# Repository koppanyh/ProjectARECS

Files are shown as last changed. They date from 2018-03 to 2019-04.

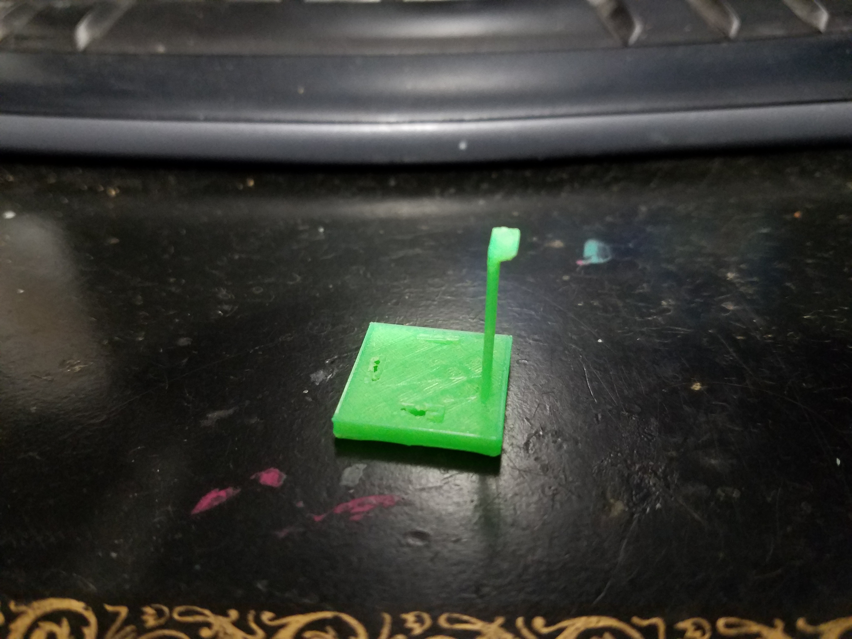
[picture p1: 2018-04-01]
seniorproject/tests/20180330_193834.jpg

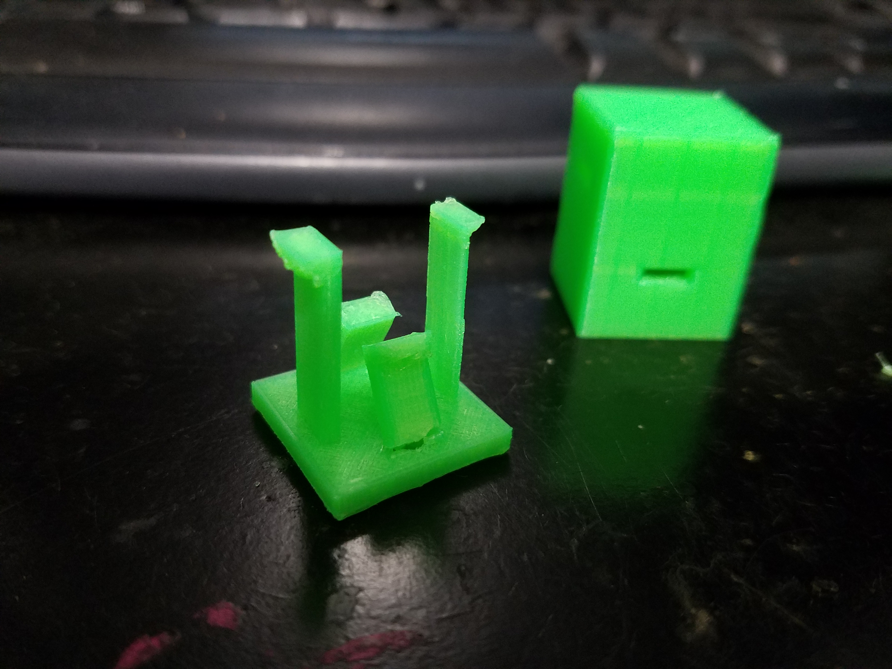
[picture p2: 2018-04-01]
seniorproject/tests/20180330_191624.jpg

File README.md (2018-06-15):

# ProjectARECS
This project is an RFID employee time tracking system.

The acronym ARECS stands for Automatic RFID Employee Clocking System.

This project is both a software and hardware project, the software is for recording and interfacing with data generated by employees, and the hardware part is the RFID nodes that generate events based on the employees.

This was initially done as a senior project during my junior year at the University of La Verne.

The version of this project submitted for the senior project can be found archived in the senior project folder. The files outside of that are the actual project files that are in active development.

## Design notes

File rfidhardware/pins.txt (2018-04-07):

esp32	rc522	piezo	dipsw	buttn	led01	power
3v3		3.3v			all**	all**
gnd		gnd								-		out-
vin												out+
d15				outer
d4				center
d2										+
d5		sda
d18		sck
d19		miso
d22		rst
d23		mosi
d32						0*
d33						1*
d34						2*
d35						3*
d25								0*

* also pulled down to ground
** all pins not directly connected to mcu

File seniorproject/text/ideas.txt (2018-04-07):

toggle thing should keep track of over/under time and give options like "cash out" or "leave early" and stuff

users can't edit records older than 7 days

rfid nodes should have button to become hotspot for on-the-spot configuration

show a super simple interface with an advanced button somewhere, clicking that advanced button will use an animation to drop down the current page and reveal the advanced page underneath

node has to keep records until verified that the server received them

in manager page, show cards of each person with picture, and hours, clicking will take to more detail page with charts and stuff

alert admins of people who just walked in

give flexible query capabilities for admins

qr codes on the id cards for quick scan

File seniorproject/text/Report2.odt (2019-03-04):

UNIVERSITY OF LA VERNE

LA VERNE, CALIFORNIA

Spring 2018

SENIOR PROJECT REPORT

J2 INNOVATIONS’ AUTOMATIC RFID EMPLOYEE CLOCKING SYSTEM

A SENIOR PROJECT SUBMITTED TO:

THE FACULTY OF

COMPUTER SCIENCE AND COMPUTER ENGINEERING

IN CANDIDACY FOR THE DEGREE OF

BACHELORS OF SCIENCE

SOFTWARE / ENGINEERING

BY

KOPPANY HORVATH

# Abstract

The purpose of this project is to design and implement an RFID based employee time tracking system for J2 Innovations, a building automation software company. The following hardware technologies were used: IOT enabled ESP 32 microcontroller, RFID scanner module, 3D printing, WiFi AP device configuration. In addition, a variety of software was used: Arduino IDE, NodeJS framework, Ractive library, AM Charts library, MySQL database. The user experience was greatly improved and user complaints were reduced to nearly none. Possible future expansions include handling different time zones for international employees, generating reports and charts for management, and scheduling days off and vacations through the UI.

# Chapter I: Introduction

## Introduction

When tasked with overseeing employee work times and productivity, how that data is obtained and managed can be the difference between a good or bad user experience. The point of this study is to design and implement a system that can improve how employees log their work hours and tasks, along with making it easy for management to manage that information. The proposed design directly relates to the problem in that it attempts to solve the problems present in the previous system for tracking employee work times. This study relates to previous work in that it uses RFID technology to acquire parts of the data, but it is applied to tracking the time of employees rather than tracking the locations of materials.

## Problem Statement

The employees and management working for J2 Innovations, a building automation software company, are frequently annoyed by the current time tracking system being used. One of the biggest problems that management complains about is that the system is a third party service that requires monthly payment per registered employee, and is not flexible in terms of adding new features or correcting problems with the service. An issue that bothers the employees is that with the current system employees have to manually type in their starting time and ending time which sometimes results in inaccurate information if an employee can't remember their starting time accurately. The project manager is sometimes bothered by not being able to see what the general schedule is for part time employees who have very dynamic schedules through the web interface of the current system. Employees also don’t like having to submit a daily email containing their work for the day along with a weekly email containing not only the information from the daily emails, but what their times were for each day that they worked because the current system has no easy way for management to view this information.

## Purpose Statement and Rationale

The purpose of this project is to design and build an RFID based employee time tracking system to address the issues caused by J2 Innovations’ current time tracking system. This new system will solve the problem of monthly payment by running on a local server rather than as a remote paid service and will solve the problem of being inflexible by being made open source and being designed to be easily modifyable. This system will also solve the problem of employees having to manually type their times by using RFID technology to automatically record that information by swiping an RFID card on an RFID node. The web interface for this system will also allow management to view the schedules of employees and view their times along with the tasks they did throughout the day.

## Method

The method of this study consisted of doing initial research to see what previous approaches to the problem had been attempted. Then more research followed to investigate a good way to implement the server software which would work to manage data and route data where it needs to be. Then research was done to see what kind of IOT configurations are generally easy to use.

After research, software implementation testing followed to determine the effectiveness of the chosen implementation. Shortly after software implementation began, the focus changed to hardware testing to see how well the components would fit together and to learn the concepts of IOT programming which would be used in the final hardware product.

Following hardware and software testing, production level implementations began. Hardware had the highest initial priority, with software coming in second in order to provide any web API support that the IOT part of the hardware required. After hardware had been finished, it was tested in 2 physical locations to make sure it worked. The software implementation continued on after that to implement all basic functionality needed by the end users.

## Need of Such a Project

This project was necessary in order to address the problems described in the Problem Statement section. Most important of those problems was to make a dynamic system that did not require payment to a 3rd party service which increases in proportion to the amount of employees using the system. This problem alone justifies the need for such a project as far as management is concerned. A quick poll of the employees also reveals that they collectively do not like the current system and even though they are skeptical about the effectiveness of this new system, they would still be willing to try the new system.

## Contributions to Knowledge and Society

Unfortunately, due to the limited nature of the Senior Project, this project does nothing particularly special to contribute to humanity's collective knowledge. However, this project has been open-source since the start and is freely available on GitHub. It is hoped that this project might be used at other companies where a free employee time tracking system would be beneficial along with all the convenience features that it provides.

## Limitations

The major limitations of this project in its current state are as follows. End users from different timezones other than the one that the server is being hosted at will notice that some of the timestamps will be incorrect. Management still doesn't have fine control over individual reports as the current implementation focuses on mass reports and data. From an IT standpoint, someone well versed in Linux based server systems will be required to install and maintain the server software. These issues are expected to be resolved in future updates of this project.

# Chapter II: Literature Review

## Historical Implementations

In conducting research, three notable implementations of digital employee time tracking systems were found. The first, Office Timesheet 2000, has the capability to clock workers in and out, along with being able to record time spent working on separate projects or tasks. The interface comes as a desktop application or as a primitive “web app”. Timesheet 2000 uses a client-server architecture with the ability to store data in a variety of database applications. This system also supports dynamic reports and the capability to send automatic email notifications (Feibus).

The second time tracking system, TimeSheet Pro, is very similar to Office Timesheet 2000 in its main features, but is designed to be more configurable. This system can either use database applications to store data, or it can store data locally. Like Timesheet 2000, TimeSheet Pro can track projects and tasks and be accessed through a web browser. Unlike Timesheet 2000, TimeSheet Pro is more configurable in terms of holidays, task rules, and pay rules. TimeSheet Pro is also considered more difficult to use due to poor design of the user interface (Feibus).

The third time tracking system is called Employee Proj Clock. This system is designed as a small desktop application that communicates with a server to retrieve and transfer information. Each user can only edit their own information, or an administrator can edit anyone's information. The interface is simple in that the basic inputs are the project to be worked on, who the user is, when they started, when they ended, and any comments the user might have. This information is sent to the server and recorded into a database. A custom reports tool allows reports to be built based on what information is required. It is reported that Employee Proj Clock improves productivity and accuracy of time records when switching over from traditional time cards or manual reporting (Gruber).

## Modern Implementations

During research, three modern examples of employee time tracking systems were discovered. The first, Syspro ShopClock, is a real-time data collection system for employee time and attendance. ShopClock can also track the time spent on jobs and materials used in performing a task. This system gives management a GANTT chart that updates in real time to display the status of employees. ShopClock allows for shifts, labor rates, and overtime pay to be defined in advance. ShopClock can also integrate with barcode readers to update the materials used and current inventory. When employees are clocking in or out, ShopClock will alert the user if there is a problem with the information that they are inputting (Syspro).

The second system is Replicon's Cloud Clock, which is a cloud based time clock. This implementation is unique in that it uses an internet connected hardware clock that the users interact with while giving management the power to monitor who clocks in and when. Along with the hardware clock, Replicon offers its Cloud Clock software as a service. This allows management to validate attendance records and ensure compliance of work policy. Replicon reported that compliance for employees submitting completed timesheets increased by 85% while reducing payroll errors from 8% to just 1.9% in less than a year (Replicon).

The last example is the TSheets employee time tracking system. What is unique about this system is how much effort the developers put into making the system as fun and easy to use as possible. TSheets has moved away from relying on dedicated hardware for tracking time and instead uses a cloud based solution with phone apps and web apps so that employees can use any device they want to clock in and out. TSheets also logs employees locations as they use the system so that employees can't cheat on attendance reports because management will know that they weren't really where they said they were when they clocked in. TSheets even has a rating system so that they can know how satisfied employees are with the overall system and its features (Computers).

## RFID Systems

Due to this project using RFID technology, research on examples of using RFID technology on humans was necessary. Unfortunately, using RFID for the purpose of tracking employee times does not seem to be something that has been reported in any journals, and thus the following examples are used for purposes other than employee time tracking. The first example is a study trying to determine the best way of utilizing RFID technology in a hospital setting to track tools and equipment throughout the building as well as patients. Of greatest interest in this study were the results and conclusions that the research group came up with while reviewing different RFID implementations. In the comparison between active and passive RFID technology, it was found that while passive RFID has a smaller detection range, it is still a better option due to the RFID tags being smaller and cheaper when compared to active RFID tags. During testing with actual passive RFID hardware, the researchers found out that the RFID tags could only be read when the face of the tag was parallel to that of the RFID reader, and it had trouble being read when in direct contact with a human body or when it was attached to some objects with a high liquid content. Eventually it was discovered that passive RFID technology has many limitations, but is acceptable because of the cost and size factors (Najera).

The second example is a study attempting to determine the effectiveness of RFID technology in collecting data from a construction site in order to be analyzed for better decision making to improve productivity. Like the previous study, the researchers in this study came to the same conclusion that passive RFID technology was better suited than active RFID technology because the tags are smaller and cheaper, even despite certain problems caused by RFID signals being attenuated by metal beams within the walls of the construction site. Also like the previous study, these researchers found that passive RFID technology has a relatively small detection range, but they were able to solve this problem by strategically positioning the RFID readers in places that would come as close as possible to where materials and workers with tags would be passing by such as doorways (Costin).

# Chapter III: Analysis

## Feasibility Study

In studying other works to determine the feasibility of this project, along with what requirements are needed for this project, a conclusion was reached in that this project is quite feasible. This conclusion was reached because all of the necessary hardware and software technologies could be found as commercial off-the-shelf modules and libraries that would make implementation of this project possible within the deadline of the Senior Project.

## Analysis of Findings From Previous Chapter

Based on the research from the previous chapter, there are common patterns that seem to be standard of employee time tracking systems. The biggest commonality that stuck out was the use of client-server architecture when implementing such a system. One of the systems, TimeSheet Pro, had the ability to store data locally, but could also use a remote database if necessary. Otherwise, the other systems exclusively used a client-server setup to keep the stored data centralized on a server and give the end users either a web interface to work with, or API calls for desktop applications that interface with the server.

The next most common implementation feature was the use of a web page interface to interact with the employee time tracking system. With the exception of Employee Proj Clock, the other platforms at least offered some form of web interface, even if a desktop application was the main interface for that system. In comparing the more modern systems with the older systems, it appears that a web app style interface is preferred over a desktop application style interface.

One smaller common feature that was found to be common during research is adding features other than employee time tracking. This seems to give the system a greater market advantage because everything can be managed with one system as opposed to multiple systems. Examples of this are tying it into the inventory system as in SysPro's ShopClock. Another example is tying in physical time tracking hardware as in Replicon's Cloud Clock.

In terms of RFID technology implementation, a preference between the two RFID types was detected as well. With RFID technology, there are two kinds, active and passive. Active RFID transmits data from the RFID tag to the RFID scanner, passive RFID is powered by the RFID scanner and communicates through backscattering. Because active RFID transmits by itself, it requires a power source such as a battery, which when compared to passive RFID, makes it a very bulky option since passive RFID is capable of data transfer without having any on-board power. Unfortunately, since passive RFID is wirelessly powered through the RFID scanner and does not broadcast by itself, the data transfer distance is very short, usually a few centimeters for low cost off-the-shelf modules.

## Hardware and Software Choices

After understanding the basics of an employee time tracking system along with the basics of RFID implementations, choices can now be made about the kind of hardware and software that would be needed to accomplish a project that combines both together. Because the software is going to be supporting the hardware in this project, it would be helpful to know about the hardware first. For RFID communication, a passive approach is preferred due to its low cost. The MFRC522 RFID module satisfies this requirement and is commercially available, even at the hobbyist level. Since the RFID node will also need some data processing capabilities along with network communication to send data to a main server, the decision to go with the ESP32 microcontroller was made. This microcontroller is relatively cheap, has WiFi networking capabilities, is easy to program, and is also commercially available.

With the main hardware components having been chosen, choosing what software to use comes next. Because of the need of a main server that the hardware will communicate to and that users will interface with, the Node.js framework was chosen. This allows for the customization of every aspect of the web server and the API that will be needed to manage everything. Since the server will also be used for serving up the web interface for the users, the standard languages of the web will be used, HTML, CSS, and JavaScript. In order to facilitate faster development of the interface, a dynamic template framework known as Ractive will be used on the client side as well. For data storage, a MySQL database will be used due to its proven reliability and ubiquity.

# Chapter IV: Design

## Overview

In order to put the pieces together and build this project, everything had to be designed first. Since there is an idea of how the users will use the system, that provides an entry point into the basic system design. The user will scan their RFID card with the RFID node. The RFID node will report to the server that the user has just scanned their card. The server will clock the user in for the day. From there the user can use the web interface from the server to interact with the data. A diagram of this basic architecture can be found in Appendix C as Figure 1.

Knowing what the architecture of this project is helps to generate a workflow for the users, which in turn will help to better design the software to meet the workflow. Figure 2 in Appendix C shows the basic workflow of the user. When users walk into work in the morning, they scan their RFID card with the RFID node. This clocks the user in and allows them to start working. As the user works on tasks or projects that they have been assigned, the user can use the web interface to log them individually. This gives management a better idea of what was done between clocking in and clocking out that day. Once the user has finished working for the day, the user scans his card as he walks out to indicate that he is clocking out. The next day the cycle is repeated and the system keeps track of it all.

## RFID Hardware

Having defined the functionality of the hardware of this project, it can now be designed fully. The hardware, referred to as “the RFID node”, must be able to scan the user's RFID card when presented with it, and report this to the server for recording purposes. As is generally considered good design, the hardware should also provide some sort of feedback to the user if scanning and reporting to the server was successful or if it had failed.

In the Hardware and Software Choices section of Chapter III, two of the main hardware components were already described. The first was the MFRC522 RFID module, this is the part that will be able to read the unique serial number from an RFID card so that it knows which user has been scanned in. The second was the ESP32 microcontroller, this part interfaces with the RFID module, does whatever processing is required of the data, then packages it up and sends it to the server to be recorded.

However, more components are needed since these two alone do not provide feedback to the user, nor do they provide any form of reconfigurability of the hardware. To address the issue of feedback, it would be best to have both auditory feedback and visual feedback in the event that the user either can't hear the feedback (due to environmental noise) or cannot see the feedback (due to not having a line-of-sight) to the device. The simplest and most common choice for visual feedback is an LED, this would allow it to blink with certain patterns based on what type of feedback the RFID node is trying to convey. For auditory feedback a small speaker would work to provide different tones that hint at states like success or failure. This small speaker is chosen to be a piezoelectric disk speaker due to its extremely low profile and low power use.

To address the problem of hardware reconfigurability, buttons and switches are the simplest and most intuitive interfaces. In the case of this RFID node design, a 4-bit DIP switch would be sufficient for providing 16 total user-defined values to give the hardware a unique address. A momentary push button would also provide the mechanism with which to launch the RFID node into access point mode so that it can be configured over WiFi.

In Appendix C, Figure 3 is a block diagram that shows how all the hardware components will be connected together. Since this RFID node will be running on electricity, a power jack and voltage regulator have been added as well to supply the energy needed to run all parts of the RFID node. The diagram shows the LED and speaker as outputs of the system. The RFID module, DIP switch, button, and voltage regulator are shown as inputs to the system. The system itself is run by the ESP32 microcontroller which is shown in the center of the diagram. This is the piece which will be accepting the inputs and delivering the outputs.

## RFID Firmware

Of course, the hardware cannot just automatically know how to work together when there is a microcontroller in the middle, therefore firmware is needed to tell the microcontroller how to coordinate everything. The firmware must be able to get the data from the RFID module, prepare it for transmission to the server, then send it to the server. While this is happening, the firmware must also be able to control the LED and speaker to alert the user as to the current state of the RFID node. Since the RFID node is designed to be configured over WiFi, an access point mode must also exist within the firmware that can be triggered from the normal operation mode.

Figure 4 in Appendix C is a flow chart that shows the basic operation of the RFID firmware. This flow chart does not include details about certain implementation details, or details about error handling modes. Initially, the mode of the RFID node doesn’t matter until after it boots up. On boot, the firmware gets the state of the DIP switch to get the user-defined 4 bit number in hexadecimal. Then the on-chip unique identifier gets read and has its least significant nibble replaced with the 4 bit DIP switch number. Then the firmware causes the speaker to make a generic beep to indicate that it successfully booted up.

After this point, the firmware looks into persistent memory to see which mode it should be in, either normal RFID scanning mode or access point configuration mode. If the mode is scanning mode, then the firmware reads the WiFi SSID, WiFi password, address of the time tracking server, and server port from the persistent memory and stores them into string variables. Then the firmware connects to the specified WiFi network. If connection is unsuccessful, then the firmware will give a failure beep and go into a loop where the LED blinks SOS in morse code and tries to connect to the WiFi over and over (this an error mode not in Figure 4).

Once a WiFi connection is established, the firmware will attempt to contact the time tracking server to get the current time. If the server cannot be reached, the firmware will make a failure beep and use a Unix timestamp of 0, it will periodically attempt to contact the server to get the current time (this is an error mode not in Figure 4). Then the firmware will create a queue to store up to 256 RFID scan records in the event that they could not be communicated to the server immediately (not in Figure 4).At this point there will be another general beep to alert the user that the RFID node is ready to start scanning RFID cards.

The firmware then enters a loop where it first checks to see if the access point configuration button has been pressed. If it has been pressed, then the firmware will set the mode record in persistent memory to be access point mode, then it will give a general beep 3 times to indicate that it is preparing to go into access point mode. Then it reboots the node so that it may go through the boot process and get to the point where it checks which mode to be in. More on the access point mode will be discussed after the general operation mode is discussed.

After checking the access point button, the firmware asks the RFID module if there is a card waiting to be scanned. If so, then the LED is turned off to show that the RFID card is being read, a scan beep is made, a RFID scan record is made containing the time the card was scanned along with the serial number of the card, the record is sent to the server, then the LED is turned back on. If the server replies that the scan was invalid, then an error beep is made. If the RFID scan record could not be sent to the server, it will be stored in the queue and an error beep will be made (this is an error mode not in Figure 4).

The firmware then continues the loop by checking to see if it has been an hour since the time was last updated or if the time was not updated during boot. If so, then the time is requested from the server and updated (not in Figure 4). Following this, the firmware checks the queue to see if there are any unsent RFID records and attempts to send them if possible (this is an error mode not in Figure 4). The loop then starts from the beginning after this point.

As stated above, the access point mode can be discussed after the general operation mode. After the first general boot beep, when the firmware is checking the mode to see which mode to start, if the mode is access point configuration mode, then the firmware runs the other half of the code. The first thing it does in access point mode is to generate an SSID with the form of “Arecs_Node_X” where X is the uppercase hexadecimal value of the DIP switch nibble (not in Figure 4). Then it generates a password with the form “passwordX” where X is the same uppercase hexadecimal value (not in Figure 4). With this SSID the firmware becomes a WiFi access point that broadcasts the SSID which can be connected to with the password.

After starting the access point, the firmware then sets up the web interface and all the API calls that are needed to support the web interface and apply configuration options. The web interface, which can be seen as Figure 5 in Appendix C, shows the modified unique identifier, inputs for the WiFi network to connect to, and inputs for the RFID server to connect to. The API calls that the web interface has access to can be seen in Figure 6 of Appendix C. The web interface uses a JavaScript AJAX call to “/getssids” to get a list of WiFi networks that the RFID node can connect to, this populates the WiFi network selector in Figure 5.

Once the configuration web interface has been filled out, clicking “Save Configuration” (Figure 5) will send the data as a POST request to the “/configure” API call. This will save the WiFi options if both password fields have been filled out. If the passwords do not match, then it will redirect to the web interface for correction (not shown in Figure 6). The “/configure” API will also save the RFID server parameters if the address of the server is filled in. Once finished, it will set the mode to be scanning mode and then return a web page to prompt a node restart in order to apply the changes. Clicking restart will call the “/restart” API call and restart the server so it may start up in scanning mode.

After defining the web interface and API calls, the firmware then starts up a DNS server. This is so that navigating to any website while connected to the access point will direct you to the configuration web interface page, this technique is known as a captive portal. The firmware will then cause a specific access point beep and blink the LED slowly to let the user know that the access point is up and ready to be connected to. The firmware continues this until the user submits the configuration and restarts the node.

## RFID Enclosure

After the hardware had been designed, it was obvious that it would need to be put into an enclosure to protect it from the users and to give it a professional appearance. A tool-less approach to the enclosure was preferred as this would allow for ease of maintenance and configuration of the DIP switch without requiring tools or force to open the enclosure. With this tool-less requirement, a snap-fit mechanism seemed obvious for holding the enclosure together and making it easy to open without tools. It works by having a base with flexible beams with something like a hook at the end that gets caught in indentations in the lid (refer to Figure 7 of Appendix C). They can then be opened by pushing the beams inward to release the hooks from the indentations.

After a bit of design and testing of snap-fit mechanisms (more about this in the RFID Enclosure section of the Implementation chapter), a final snap-fit test piece was designed and made. The outline of the design of this test piece can be seen as Figure 7 of Appendix C, and the piece made from the design can be found as Figure 8. Unfortunately, this piece broke during a demonstration and was no longer considered a valid design, especially when combined with the failure of previous snap-fit tests (more on this in the Implementation chapter).

A new design was needed to replace the snap-fit concept, but that would still provide the tool-less features of the snap-fit mechanism. This new design was inspired by the snap-fit mechanism and a latch mechanism. The final version of this design can be found as Figure 9 of Appendix C. This new mechanism to hold the enclosure together is referred to as a pin-lock or pin-latch mechanism, but the true name of this mechanism is unknown since mechanisms similar to it could not be found. This mechanism also went through a few design and test stages before leading to this final version (more on this in the Implementation chapter).

The pin-latch mechanism works by having one side of the lid (light gray on the left of Figure 9) held down by something like a reinforced snap-fit joint that doesn't actually snap (dark gray on the left of Figure 9). The lid is able to somewhat hinge on and off of this reinforced snap when the pin (black on the right of Figure 9) is not present. When the pin is present, it prevents the right side of the lid from lifting off of the base (dark gray of Figure 9), and therefore it cannot hinge open and disengage from the snap on the left. The pin uses a snap-fit mechanism to hold itself in place, but this is not a load-bearing snap-fit joint. An image of a physical test piece using this design can be found as Figure 10 of Appendix C.

With the mechanism to hold the enclosure together figured out, the actual enclosure of the RFID hardware could finally be designed. The layout was designed by arranging the hardware components on a piece of paper until a compact and efficient layout was found (Figure 11 of Appendix C). The final design for this enclosure can be found as Figure 12 of Appendix C. The basic design consisted of a base where the electronics would be mounted on (green on Figure 12), a lid to cover everything up (gray on Figure 12), a riser to hold the RFID module close to the surface of the lid (blue on Figure 12), and the pins of the pin-latch mechanism (yellow on Figure 12).

The area of the base (green) was estimated based on how much space the hardware components took up from the layout in Figure 11 of Appendix C. The base also has holes on it for mounting to a wall, these were designed from measurements taken of the mounting holes of a household smoke detector. There is a hole roughly in the middle for the access point configuration button. There are also the reinforced snaps and the second set of holes for the pins that came from the test design. Finally, the base has a large protrusion between the two pin holes for mounting the power jack.

The lid (gray) has the two holes for the pins, along with a bigger hole in the middle for the power jack to stick out of. There is a hole to the side of the pin holes used for connecting a debug cable to the ESP32 microcontroller in the event that debugging or re-flashing of the firmware is required. The back of the lid has two slots for each of the snaps to hook into.

The pins (yellow) of the enclosure are the exact same design as used by the test piece. The riser (blue) for the RFID module is just a slanted flat surface (to give the crystal oscillator some space under the lid) with legs that have a little extra material at the bottom for gluing to the base.

## Server and Web Software

Since the hardware is not designed to be a standalone product, a server is needed to process and handle the data generated by the RFID nodes. Since that data is also useless unless it can be accessed and manipulated, a front end to the server is required as well.

*talk about database design first

*server designed to be configured with db.key file

(elaborate on logic and how you programmed everything)

(the way everything works)

(flow charts, explain them)

(what algorithms and why)

Chapter V: Implementation

RFID Hardware

RFID Firmware

RFID Enclosure

*during implementation it was learned that pla plastic was too rigid to provide the flexibility for snap-fit

Server and Web Software

Chapter VI: Conclusion

Summary and Conclusion

Data

Discussion

Implications

Personal Reflection

Lessons Learned

If It Had To Be Redone

Future Research and Recommendations

Project Recommendations

# References

Computers, software; employees and employers share the love with online time tracking. 2013. Computer Weekly News, May 02. http://0- search.proquest.com.leopac.ulv.edu/docview/1341082761?accountid=25355.

Costin, Aaron, et al. “Leveraging Passive RFID Technology for Construction Resource Field Mobility and Status Monitoring in a High-Rise Renovation Project.” Automation in Construction, vol. 24, July 2012, pp. 1–15., doi:10.1016/j.autcon.2012.02.015.

Feibus, Andy. 1999. Automated time-trackers. InformationWeek no. 742: 53-56, http://0- search.proquest.com.leopac.ulv.edu/docview/229141683?accountid=25355.

Gruber, Elizabeth M. 2001. Project time tracking. Modern Machine Shop 74, no. 1: 203, http://0- search.proquest.com.leopac.ulv.edu/docview/213704139?accountid=25355.

Najera, Pablo, et al. “Real-Time Location and Inpatient Care Systems Based on Passive RFID.” Journal of Network and Computer Applications, vol. 34, no. 3, May 2011, pp. 980–989., doi:10.1016/j.jnca.2010.04.011.

Replicon releases cloud clock for tracking employee time. 2011. Wireless News, http://0- search.proquest.com.leopac.ulv.edu/docview/904432535?accountid=25355.

Syspro rolls out real-time employee tracking solution. 2007. Wireless News: 1, http://0- search.proquest.com.leopac.ulv.edu/docview/210111631?accountid=25355.

Appendices

Appendix A: Gantts Chart

Appendix B: Source Code

Appendix C: Diagrams

Figure 1: Basic system architecture

Figure 2: Non-management employee workflow

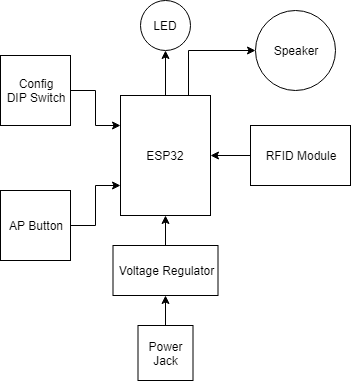
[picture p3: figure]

Figure 3: RFID hardware connection block diagram

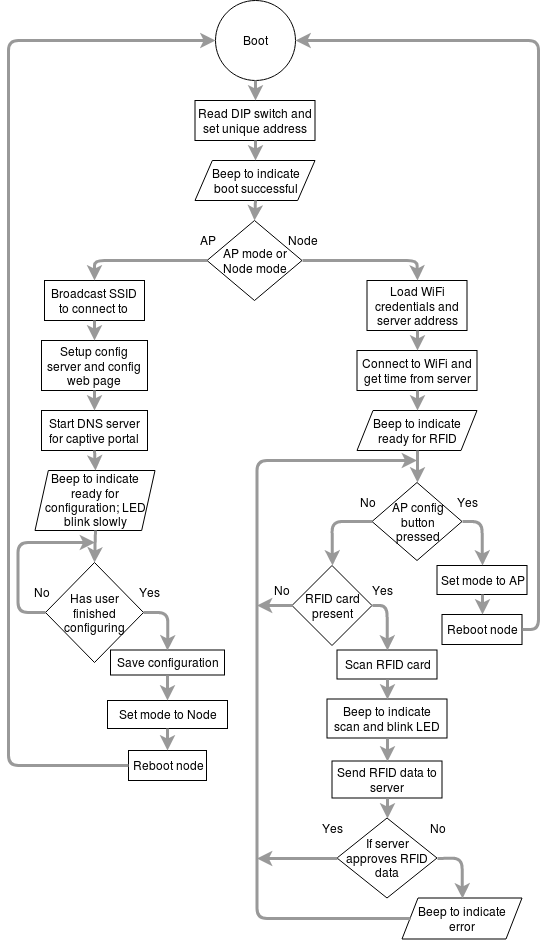
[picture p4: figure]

Figure 4: Firmware flowchart for RFID node

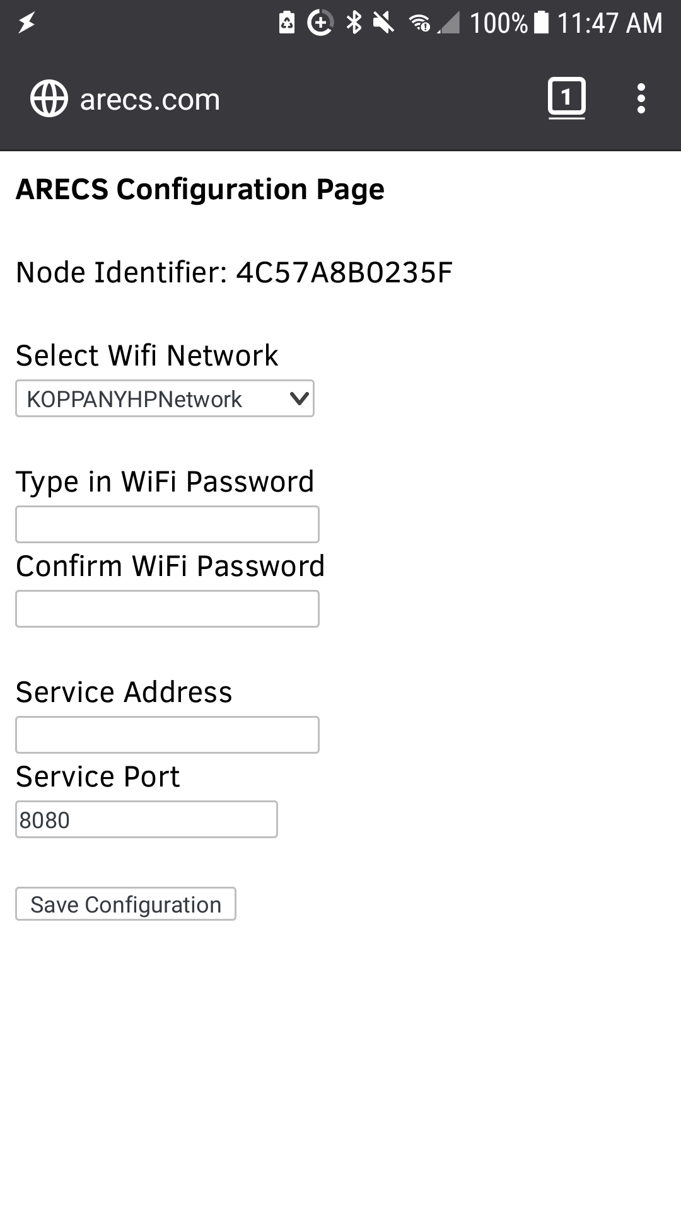
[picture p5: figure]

Figure 5: AP configuration web interface

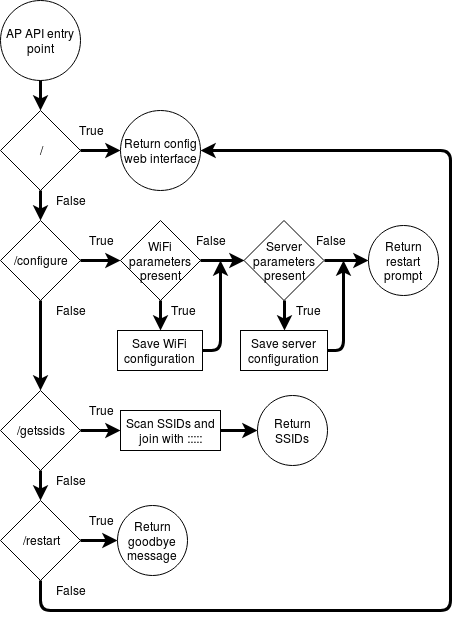
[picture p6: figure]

Figure 6: API flowchart for RFID node AP firmware

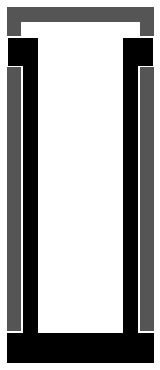
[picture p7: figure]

Figure 7: Design of snap-fit test piece

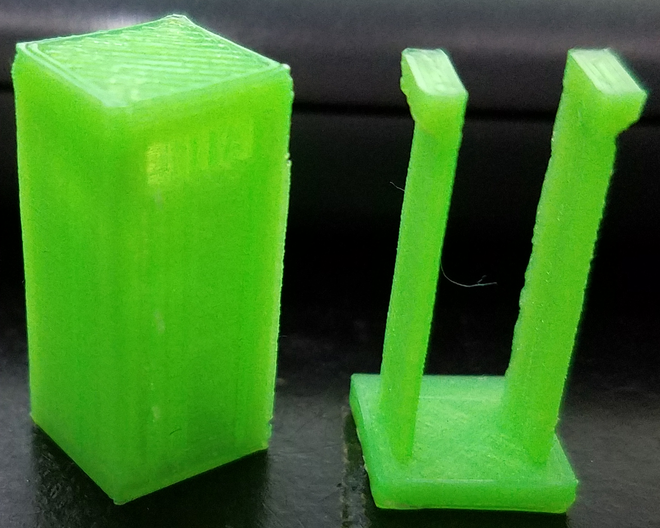
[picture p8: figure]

Figure 8: Physical snap-fit test piece

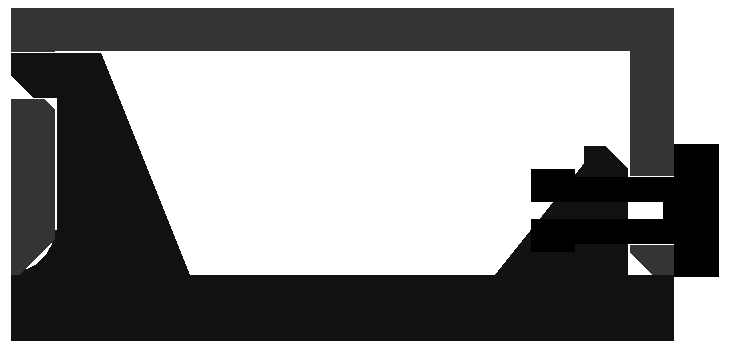
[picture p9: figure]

Figure 9: Design of pin-latch test piece

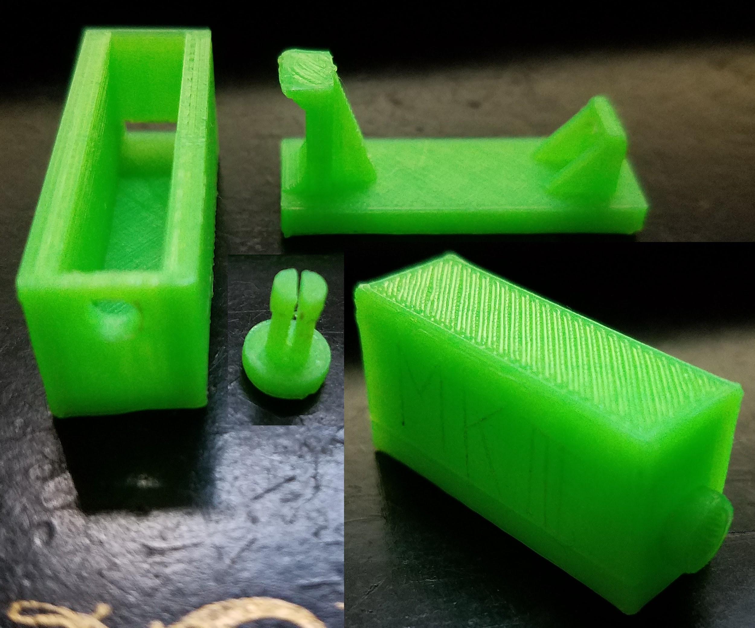
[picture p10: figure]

Figure 10: Physical pin-latch test piece

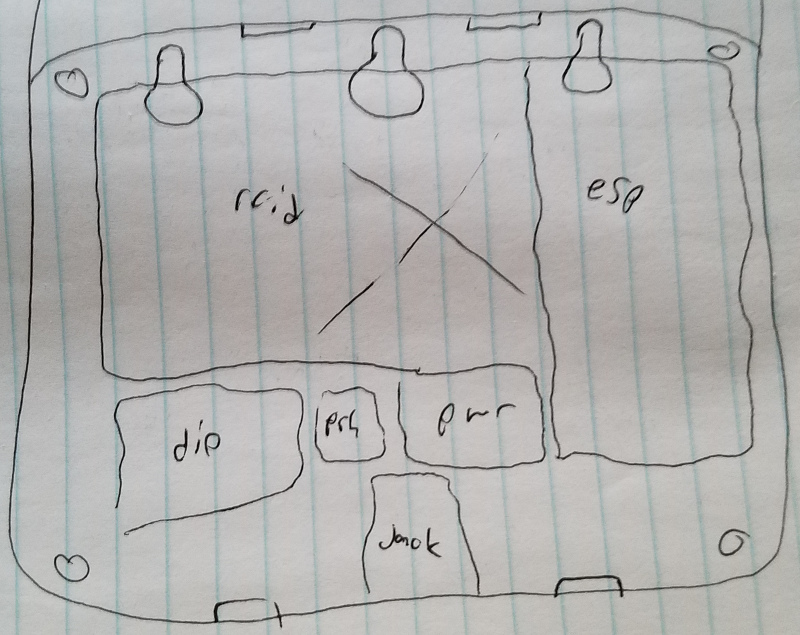
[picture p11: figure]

Figure 11: Hardware layout designed on paper

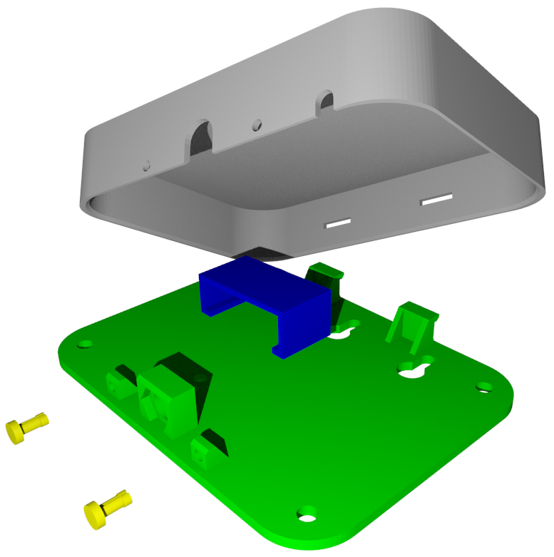
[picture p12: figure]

Figure 12: Enclosure design using pin-latch mechanism

Appendix D: Proposal

Appendix E: PowerPoint

J2 INNOVATIONS’ AUTOMATIC RFID EMPLOYEE CLOCKING SYSTEM ii

Koppany Horvath 2019-03-03

J2 INNOVATIONS’ AUTOMATIC RFID EMPLOYEE CLOCKING SYSTEM 28

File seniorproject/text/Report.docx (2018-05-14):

# UNIVERSITY OF LA VERNE

# LA VERNE, CALIFORNIA

# Spring 2018

# SENIOR PROJECT REPORT

J2 INNOVATIONS’ AUTOMATIC RFID EMPLOYEE CLOCKING SYSTEM

# A SENIOR PROJECT SUBMITTED TO:

# THE FACULTY OF

# COMPUTER SCIENCE AND COMPUTER ENGINEERING

# IN CANDIDANCY FOR THE DEGREE OF

# BACHELORS OF SCIENCE

# SOFTWARE / ENGINEERING

# BY

# KOPPANY HORVATH

# Abstract

The purpose of this project is to design and implement an RFID based employee time tracking system for J2 Innovations, a building automation software company. The following hardware technologies were used: IOT enabled ESP (Whitby & Neely, 2018) 32 microcontroller, RFID scanner module, 3D printing, WiFi AP device configuration. In addition, a variety of software was used: Arduino IDE, NodeJS framework, Ractive library, AM Charts library, MySQL database. The user experience was greatly improved and user complaints were reduced to nearly none. Possible future expansions include handling different time zones for international employees, generating reports and charts for management, and scheduling days off and vacations through the UI.

# Introduction

Keeping accurate records of employee work times is very important. Not only does it ensure that the employees get paid for what they worked, but it also makes sure that conflicts arising from accidental overpaying or underpaying do not occur. Accurate time records also allow for the possibility of measuring work performance when coupled with descriptions of what was done during those hours. Using this information to modify the working environment and schedules can lead to higher productivity in a company.

- What is the point if the study?
- How does the proposed design relate to the problem?
- What are the implications of the study, and how does the study relate to previous work in the area?
- What are current pro[positions tested, and how were they derived?

A good introduction answer these questions in a paragraph or two and, by summarizing the relevant arguments and the data, gives the reader a firm sense of what was done and why.

Develop the background:

Assume that the reader has knowledge in the field for which you are writing and does not require a complete digest. A scholarly review of earlier work provides an appropriate history and recognizes the priority of the work of others. If you summarize earlier works, avoid nonessential details; instead, emphasize pertinent findings, relevant methodological issues, and major conclusion. Refer readers to general surveys or reviews of the topic if they are available. Demonstrate the logical continuity between previous and present work.

State the purpose and rationale:

After you have introduced the problem and developed the background material, you are in a position to tell what you did. Make this statement in the closing paragraph of the introduction.

# Method

Insert method here

# Results

Insert results here

# Discussion

Insert discussion here

# References

# Bibliography

Whitby, S., & Neely, M. (2018). this is a play. MIS Quarterly, 7(2), 9.

# Appendix

Insert appendix here

Koppany Horvath 2018-05-04

J2 INNOVATIONS’ AUTOMATIC RFID EMPLOYEE CLOCKING SYSTEM Page 5 of 6

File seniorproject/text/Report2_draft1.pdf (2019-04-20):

UNIVERSITY OF LA VERNE

LA VERNE, CALIFORNIA

Spring 2019

SENIOR PROJECT REPORT

J2 INNOVATIONS’ AUTOMATIC RFID EMPLOYEE CLOCKING SYSTEM

A SENIOR PROJECT SUBMITTED TO:

THE FACULTY OF

COMPUTER SCIENCE AND COMPUTER ENGINEERING

IN CANDIDACY FOR THE DEGREE OF

BACHELORS OF SCIENCE

SOFTWARE / ENGINEERING

BY

KOPPANY HORVATH

J2 INNOVATIONS’ AUTOMATIC RFID EMPLOYEE CLOCKING SYSTEM | i

## Abstract

The purpose of this project is to design and implement an RFID based employee time

tracking system for J2 Innovations, a building automation software company. The following

hardware technologies were used: IoT enabled ESP 32 microcontroller, RFID scanner module,

3D printing, WiFi AP device configuration. In addition, a variety of software was used: Arduino

IDE, NodeJS framework, Ractive library, AM Charts library, MySQL database. The user

experience was greatly improved and user complaints were reduced to nearly none. Possible

future expansions include handling different time zones for international employees, generating

reports and charts for management, and scheduling days off and vacations through the UI.

Koppany Horvath | 2019-04-19

J2 INNOVATIONS’ AUTOMATIC RFID EMPLOYEE CLOCKING SYSTEM | ii

## Table of Contents

J2 INNOVATIONS’ AUTOMATIC RFID EMPLOYEE CLOCKING SYSTEM | 1

## Chapter I: Introduction

## Introduction

When tasked with overseeing employee work times and productivity, how that data is

obtained and managed can be the difference between a good or bad user experience. The point of

this study is to design and implement a system that can improve how employees log their work

hours and tasks, along with making it easy for management to manage that information. The

proposed design directly relates to the problem in that it attempts to solve the problems present in

the previous system for tracking employee work times. This study relates to previous work in

that it uses RFID technology to acquire parts of the data, but it is applied to tracking the time of

employees rather than tracking the locations of materials.

## Problem Statement

The employees and management working for J2 Innovations, a building automation software

company, are frequently annoyed by the current time tracking system being used. One of the

biggest problems that management complains about is that the system is a third party service that

requires monthly payment per registered employee, and is not flexible in terms of adding new

features or correcting problems with the service. An issue that bothers the employees is that with

the current system employees have to manually type in their starting time and ending time which

sometimes results in inaccurate information if an employee can't remember their starting time

accurately. The project manager is sometimes bothered by not being able to see what the general

schedule is for part time employees who have very dynamic schedules through the web interface of the current system. Employees also don’t like having to submit a daily email containing their

work for the day along with a weekly email containing not only the information from the daily

emails, but what their times were for each day that they worked because the current system has

no easy way for management to view this information.

## Purpose Statement and Rationale

The purpose of this project is to design and build an RFID based employee time tracking

system to address the issues caused by J2 Innovations’ current time tracking system. This new

system will solve the problem of monthly payment by running on a local server rather than as a

remote paid service and will solve the problem of being inflexible by being made open source

and being designed to be easily modifiable. This system will also solve the problem of

employees having to manually type their times by using RFID technology to automatically

record that information by swiping an RFID card on an RFID node. The web interface for this

system will also allow management to view the schedules of employees and view their times

along with the tasks they did throughout the day.

## Method

The method of this study consisted of doing initial research to see what previous approaches

to the problem had been attempted. Then more research followed to investigate a good way to

implement the server software which would work to manage data and route data where it needs

to be. Then research was done to see what kind of IoT configurations are generally easy to use.

After research, software implementation testing followed to determine the effectiveness of

the chosen implementation. Shortly after software implementation began, the focus changed to hardware testing to see how well the components would fit together and to learn the concepts of

IoT programming which would be used in the final hardware product.

Following hardware and software testing, production level implementations began.

Hardware had the highest initial priority, with software coming in second in order to provide any

web API support that the IoT part of the hardware required. After hardware had been finished, it

was tested in 2 physical locations to make sure it worked. The software implementation

continued on after that to implement all basic functionality needed by the end users.

## Need of Such a Project

This project was necessary in order to address the problems described in the Problem

Statement section. Most important of those problems was to make a dynamic system that did not

require payment to a third party service which increases in proportion to the amount of

employees using the system. This problem alone justifies the need for such a project as far as

management is concerned. A quick poll of the employees also reveals that they collectively do

not like the current system and even though they are skeptical about the effectiveness of this new

system, they would still be willing to try the new system.

## Contributions to Knowledge and Society

Unfortunately, due to the limited nature of the Senior Project, this project does nothing

particularly special to contribute to humanity's collective knowledge. However, this project has

been open-source since the start and is freely available on GitHub. It is hoped that this project

might be used at other companies where a free employee time tracking system would be

beneficial along with all the convenience features that it provides.

## Limitations

The major limitations of this project in its current state are as follows. End users from

different time zones other than the one that the server is being hosted at will notice that some of

the timestamps will be incorrect. Management still doesn't have fine control over individual

reports as the current implementation focuses on mass reports and data. From an IT standpoint,

someone well versed in Linux based server systems will be required to install and maintain the

server software. These issues are expected to be resolved in future updates of this project.

## Chapter II: Literature Review

## Historical Implementations

In conducting research, three notable implementations of digital employee time tracking

systems were found. The first, Office Timesheet 2000, has the capability to clock workers in and

out, along with being able to record time spent working on separate projects or tasks. The

interface comes as a desktop application or as a primitive “web app”. Timesheet 2000 uses a

client-server architecture with the ability to store data in a variety of database applications. This

system also supports dynamic reports and the capability to send automatic email notifications

(Feibus).

The second time tracking system, TimeSheet Pro, is very similar to Office Timesheet 2000

in its main features, but is designed to be more configurable. This system can either use database

applications to store data, or it can store data locally. Like Timesheet 2000, TimeSheet Pro can

track projects and tasks and be accessed through a web browser. Unlike Timesheet 2000,

TimeSheet Pro is more configurable in terms of holidays, task rules, and pay rules. TimeSheet

Pro is also considered more difficult to use due to poor design of the user interface (Feibus).

The third time tracking system is called Employee Proj Clock. This system is designed as a

small desktop application that communicates with a server to retrieve and transfer information.

Each user can only edit their own information, or an administrator can edit anyone's information.

The interface is simple in that the basic inputs are the project to be worked on, who the user is,

when they started, when they ended, and any comments the user might have. This information is

sent to the server and recorded into a database. A custom reports tool allows reports to be built

based on what information is required. It is reported that Employee Proj Clock improves

productivity and accuracy of time records when switching over from traditional time cards or

manual reporting (Gruber).

## Modern Implementations

During research, three modern examples of employee time tracking systems were

discovered. The first, Syspro ShopClock, is a real-time data collection system for employee time

and attendance. ShopClock can also track the time spent on jobs and materials used in

performing a task. This system gives management a GANTT chart that updates in real time to

display the status of employees. ShopClock allows for shifts, labor rates, and overtime pay to be

defined in advance. ShopClock can also integrate with barcode readers to update the materials

used and current inventory. When employees are clocking in or out, ShopClock will alert the user

if there is a problem with the information that they are inputting (Syspro).

The second system is Replicon's Cloud Clock, which is a cloud based time clock. This

implementation is unique in that it uses an internet connected hardware clock that the users interact with while giving management the power to monitor who clocks in and when. Along

with the hardware clock, Replicon offers its Cloud Clock software as a service. This allows

management to validate attendance records and ensure compliance of work policy. Replicon

reported that compliance for employees submitting completed timesheets increased by 85%

while reducing payroll errors from 8% to just 1.9% in less than a year (Replicon).

The last example is the TSheets employee time tracking system. What is unique about this

system is how much effort the developers put into making the system as fun and easy to use as

possible. TSheets has moved away from relying on dedicated hardware for tracking time and

instead uses a cloud based solution with phone apps and web apps so that employees can use any

device they want to clock in and out. TSheets also logs employees locations as they use the

system so that employees can't cheat on attendance reports because management will know that

they weren't really where they said they were when they clocked in. TSheets even has a rating

system so that they can know how satisfied employees are with the overall system and its

features (Computers).

## RFID Systems

Due to this project using RFID technology, research on examples of using RFID technology

on humans was necessary. Unfortunately, using RFID for the purpose of tracking employee times

does not seem to be something that has been reported in any journals, and thus the following

examples are used for purposes other than employee time tracking. The first example is a study

trying to determine the best way of utilizing RFID technology in a hospital setting to track tools

and equipment throughout the building as well as patients. Of greatest interest in this study were

the results and conclusions that the research group came up with while reviewing different RFID implementations. In the comparison between active and passive RFID technology, it was found

that while passive RFID has a smaller detection range, it is still a better option due to the RFID

tags being smaller and cheaper when compared to active RFID tags. During testing with actual

passive RFID hardware, the researchers found out that the RFID tags could only be read when

the face of the tag was parallel to that of the RFID reader, and it had trouble being read when in

direct contact with a human body or when it was attached to some objects with a high liquid

content. Eventually it was discovered that passive RFID technology has many limitations, but is

acceptable because of the cost and size factors (Najera).

The second example is a study attempting to determine the effectiveness of RFID

technology in collecting data from a construction site in order to be analyzed for better decision

making to improve productivity. Like the previous study, the researchers in this study came to the

same conclusion that passive RFID technology was better suited than active RFID technology

because the tags are smaller and cheaper, even despite certain problems caused by RFID signals

being attenuated by metal beams within the walls of the construction site. Also like the previous

study, these researchers found that passive RFID technology has a relatively small detection

range, but they were able to solve this problem by strategically positioning the RFID readers in

places that would come as close as possible to where materials and workers with tags would be

passing by such as doorways (Costin).

## Chapter III: Analysis

## Feasibility Study

In studying other works to determine the feasibility of this project, along with what

requirements are needed for this project, a conclusion was reached in that this project is quite

feasible. This conclusion was reached because all of the necessary hardware and software

technologies could be found as commercial off-the-shelf modules and libraries that would make

implementation of this project possible within the deadline of the Senior Project.

## Analysis of Findings From Previous Chapter

Based on the research from the previous chapter, there are common patterns that seem to be

standard of employee time tracking systems. The biggest commonality that stuck out was the use

of client-server architecture when implementing such a system. One of the systems, TimeSheet

Pro, had the ability to store data locally, but could also use a remote database if necessary.

Otherwise, the other systems exclusively used a client-server setup to keep the stored data

centralized on a server and give the end users either a web interface to work with, or API calls

for desktop applications that interface with the server.

The next most common implementation feature was the use of a web page interface to

interact with the employee time tracking system. With the exception of Employee Proj Clock, the

other platforms at least offered some form of web interface, even if a desktop application was the

main interface for that system. In comparing the more modern systems with the older systems, it

appears that a web app style interface is preferred over a desktop application style interface.

One smaller common feature that was found to be common during research is adding

features other than employee time tracking. This seems to give the system a greater market

advantage because everything can be managed with one system as opposed to multiple systems.

Examples of this are tying it into the inventory system as in SysPro's ShopClock. Another

example is tying in physical time tracking hardware as in Replicon's Cloud Clock.

In terms of RFID technology implementation, a preference between the two RFID types was

detected as well. With RFID technology, there are two kinds, active and passive. Active RFID

transmits data from the RFID tag to the RFID scanner, passive RFID is powered by the RFID

scanner and communicates through backscattering. Because active RFID transmits by itself, it

requires a power source such as a battery, which when compared to passive RFID, makes it a

very bulky option since passive RFID is capable of data transfer without having any on-board

power. Unfortunately, since passive RFID is wirelessly powered through the RFID scanner and

does not broadcast by itself, the data transfer distance is very short, usually a few centimeters for

low cost off-the-shelf modules.

## Hardware and Software Choices

After understanding the basics of an employee time tracking system along with the basics of

RFID implementations, choices can now be made about the kind of hardware and software that

would be needed to accomplish a project that combines both together. Because the software is

going to be supporting the hardware in this project, it would be helpful to know about the

hardware first. For RFID communication, a passive approach is preferred due to its low cost. The

MFRC522 RFID module satisfies this requirement and is commercially available, even at the

hobbyist level. Since the RFID node will also need some data processing capabilities along with network communication to send data to a main server, the decision to go with the ESP32

microcontroller was made. This microcontroller is relatively cheap, has WiFi networking

capabilities, is easy to program, and is also commercially available.

With the main hardware components having been chosen, choosing what software to use

comes next. Because of the need of a main server that the hardware will communicate to and that

users will interface with, the Node.js framework was chosen. This allows for the customization

of every aspect of the web server and the API that will be needed to manage everything. Since

the server will also be used for serving up the web interface for the users, the standard languages

of the web will be used, HTML, CSS, and JavaScript. In order to facilitate faster development of

the interface, a dynamic template framework known as Ractive will be used on the client side as

well as the AM Charts library to aid in rendering charts of employee work and progress. For data

storage, a MySQL database will be used due to its proven reliability and ubiquity.

## Chapter IV: Design and Implementation

## Overview

In order to put the pieces together and build this project, everything had to be designed first.

Since there is an idea of how the users will use the system, that provides an entry point into the

basic system design. The user will scan their RFID card with the RFID node. The RFID node

will report to the server that the user has just scanned their card. The server will clock the user in

for the day. From there the user can use the web interface from the server to interact with the

data. A diagram of this basic architecture can be found in Appendix C as Figure 1.

Knowing what the architecture of this project is helps to generate a workflow for the users,

which in turn will help to better design the software to meet the workflow. Figure 2 in Appendix

C shows the basic workflow of the user. When users walk into work in the morning, they scan

their RFID card with the RFID node. This clocks the user in and allows them to start working. As

the user works on tasks or projects that they have been assigned, the user can use the web

interface to log them individually. This gives management a better idea of what was done

between clocking in and clocking out that day. Once the user has finished working for the day,

the user scans his card as he walks out to indicate that he is clocking out. The next day the cycle

is repeated and the system keeps track of it all.

## RFID Hardware

Having defined the functionality of the hardware of this project, it can now be designed

fully. The hardware, referred to as “the RFID node”, must be able to scan the user's RFID card

when presented with it, and report this to the server for recording purposes. As is generally

considered good design, the hardware should also provide some sort of feedback to the user if

scanning and reporting to the server was successful or if it had failed.

In the Hardware and Software Choices section of Chapter III, two of the main hardware

components were already described. The first was the MFRC522 RFID module, this is the part

that will be able to read the unique serial number from an RFID card so that it knows which user

has been scanned in. The second was the ESP32 microcontroller, this part interfaces with the

RFID module, does whatever processing is required of the data, then packages it up and sends it

to the server to be recorded.

However, more components are needed since these two alone do not provide feedback to the

user, nor do they provide any form of reconfiguration of the hardware. To address the issue of

feedback, it would be best to have both auditory feedback and visual feedback in the event that

the user either can't hear the feedback (due to environmental noise) or cannot see the feedback

(due to not having a line-of-sight) to the device. The simplest and most common choice for

visual feedback is an LED, this would allow it to blink with certain patterns based on what type

of feedback the RFID node is trying to convey. For auditory feedback a small speaker would

work to provide different tones that hint at states like success or failure. This small speaker is

chosen to be a piezoelectric disk speaker due to its extremely low profile and low power use.

To address the problem of hardware reconfiguration, buttons and switches are the simplest

and most intuitive interfaces. In the case of this RFID node design, a 4-bit DIP switch would be

sufficient for providing 16 total user-defined values to give the hardware a unique address. A

momentary push button would also provide the mechanism with which to launch the RFID node

into access point mode so that it can be configured over WiFi.

In Appendix C, Figure 3 is a block diagram that shows how all the hardware components

will be connected together. Since this RFID node will be powered by electricity, a power jack

and voltage regulator have been added as well to supply the energy needed to run all parts of the

RFID node. The diagram shows the LED and speaker as outputs of the system. The RFID

module, DIP switch, button, and voltage regulator are shown as inputs to the system. The system

itself is run by the ESP32 microcontroller which is shown in the center of the diagram. This is

the piece which will be accepting the inputs and delivering the outputs. Figure 4 of Appendix C

shows the physical hardware prototype on a breadboard, but without the voltage regulator. A bill

of materials can be found in Appendix A detailing the cost of the parts needed to make one RFID node, but including enough material to build two; the parts were sourced from Ebay.com and as

such there may be more parts bought than necessary.

## RFID Firmware

Of course, the hardware cannot just automatically know how to work together when there is

a microcontroller in the middle, therefore firmware is needed to tell the microcontroller how to

coordinate everything. The firmware must be able to get the data from the RFID module, prepare

it for transmission to the server, then send it to the server. While this is happening, the firmware

must also be able to control the LED and speaker to alert the user as to the current state of the

RFID node. Since the RFID node is designed to be configured over WiFi, an access point mode

must also exist within the firmware that can be triggered from the normal operation mode.

Figure 5 in Appendix C is a flow chart that shows the basic operation of the RFID firmware.

This flow chart does not include details about certain implementation details, or details about

error handling modes. Initially, the mode of the RFID node doesn’t matter until after it boots up.

On boot, the firmware gets the state of the DIP switch to get the user-defined 4 bit number in

hexadecimal. Then the on-chip unique identifier gets read and has its least significant nibble

replaced with the 4 bit DIP switch number. Then the firmware causes the speaker to make a

generic beep to indicate that it successfully booted up.

After this point, the firmware looks into persistent memory to see which mode it should be

in, either normal RFID scanning mode or access point configuration mode. If the mode is

scanning mode, then the firmware reads the WiFi SSID, WiFi password, address of the time

tracking server, and server’s port number from the persistent memory and stores them into string

variables. Then the firmware connects to the specified WiFi network. If connection is unsuccessful, then the firmware will give a failure beep and go into a loop where the LED blinks

SOS in Morse code and tries to connect to the WiFi over and over (this an error mode not in

Figure 5).

Once a WiFi connection is established, the firmware will attempt to contact the time tracking

server to get the current time. If the server cannot be reached, the firmware will make a failure

beep and use a Unix timestamp of 0, it will periodically attempt to contact the server to get the

current time (this is an error mode not in Figure 5). Then the firmware will create a queue to

store up to 256 RFID scan records in the event that they could not be communicated to the server

immediately (not in Figure 5). At this point there will be another general beep to alert the user

that the RFID node is ready to start scanning RFID cards.

The firmware then enters a loop where it first checks to see if the access point configuration

button has been pressed. If it has been pressed, then the firmware will set the mode record in

persistent memory to be access point mode, then it will give a general beep 3 times to indicate

that it is preparing to go into access point mode. Then it reboots the node so that it may go

through the boot process and get to the point where it checks which mode to be in. More on the

access point mode will be discussed after the general operation mode is discussed.

After checking the access point button, the firmware asks the RFID module if there is a card

waiting to be scanned. If so, then the LED is turned off to show that the RFID card is being read,

a scan beep is made, a RFID scan record is made containing the time the card was scanned along

with the serial number of the card, the record is sent to the server, then the LED is turned back

on. If the server replies that the scan was invalid, then an error beep is made. If the RFID scan

record could not be sent to the server, it will be stored in the queue and an error beep will be

made (this is an error mode not in Figure 5).

The firmware then continues the loop by checking to see if it has been an hour since the time

was last updated or if the time was not updated during boot. If so, then the time is requested from

the server and updated (not in Figure 5). Following this, the firmware checks the queue to see if

there are any unsent RFID records and attempts to send them if possible (this is an error mode

not in Figure 5). The loop then starts from the beginning after this point.

As stated above, the access point mode can be discussed after the general operation mode.

After the first general boot beep, when the firmware is checking the mode to see which mode to

start, if the mode is access point configuration mode, then the firmware runs the other half of the

code. The first thing it does in access point mode is to generate an SSID with the form of

“Arecs_Node_X” where X is the uppercase hexadecimal value of the DIP switch nibble (not in

Figure 5). Then it generates a password with the form “passwordX” where X is the same

uppercase hexadecimal value (not in Figure 5). With this SSID the node becomes a WiFi access

point that broadcasts the SSID which can be connected to with the password.

After starting the access point, the firmware then sets up the web interface and all the API

calls that are needed to support the web interface and apply configuration options. The web

interface, which can be seen as Figure 6 in Appendix C, shows the modified unique identifier,

inputs for the WiFi network to connect to, and inputs for the RFID server to connect to. The API

calls that the web interface has access to can be seen in Figure 7 of Appendix C. The web

interface uses a JavaScript AJAX call to “/getssids” to get a list of WiFi networks that the RFID

node can connect to, this populates the WiFi network selector in Figure 6.

Once the configuration web interface has been filled out, clicking “Save Configuration”

(Figure 6) will send the data as a POST request to the “/configure” API call. This will save the

WiFi options if both password fields have been filled out. If the passwords do not match, then it will redirect to the web interface for correction (not shown in Figure 7). The “/configure” API

will also save the RFID server parameters if the address of the server is filled in. Once finished,

it will set the mode to be scanning mode and then return a web page to prompt a node restart in

order to apply the changes. Clicking restart will call the “/restart” API call and restart the server

so it may start up in scanning mode.

After defining the web interface and API calls, the firmware then starts up a DNS server.

This is so that navigating to any website while connected to the access point will direct you to

the configuration web interface page, this technique is known as a captive portal. The firmware

will then cause a specific access point beep and blink the LED slowly to let the user know that

the access point is up and ready to be connected to. The firmware continues this until the user

submits the configuration and restarts the node.

## RFID Enclosure

After the hardware and firmware had been designed, it was obvious that it would need to be

put into an enclosure to protect it from the users and to give it a professional appearance. A tool-

less approach to the enclosure was preferred as this would allow for ease of maintenance and

configuration of the DIP switch without requiring tools or force to open the enclosure. With this

tool-less requirement, a snap-fit mechanism seemed obvious for holding the enclosure together

and making it easy to open without tools. It works by having a base with flexible beams with

something like a hook at the end that gets caught in indentations in the lid (refer to Figure 8 of

Appendix C). They can then be opened by pushing the beams inward to release the hooks from

the indentations.

After a bit of design and testing of snap-fit mechanisms, a final snap-fit test piece was

designed and made. The outline of the design of this test piece can be seen as Figure 8 of

Appendix C, and the piece made from the design can be found as Figure 9. Unfortunately, this

piece broke during a demonstration and was no longer considered a valid design, especially

when combined with the failure of previous snap-fit test pieces. This was due to the fact that the

plastic parts were printed from PLA plastic, which is a strong but brittle plastic that could not

flex enough for snap-fit joints without breaking. The breakage would normally occur at the base

of the snap joint’s arm (Figure 10 is an example of this).

A new design was needed to replace the snap-fit concept, but that would still provide the

tool-less features of the snap-fit mechanism. This new design was inspired by the combination of

the snap-fit mechanism and a latch mechanism. The final version of this design can be found as

Figure 11 of Appendix C. This new mechanism to hold the enclosure together is referred to as a

pin-lock or pin-latch mechanism, but the true name of this mechanism is unknown since

mechanisms similar to it could not be found. This mechanism also went through a few design

and test stages before leading to this final version. Figure 12 highlights some of the changes in a

later design to eliminate the breakage seen in the older version of the pin-latch, those structures

were added to support and disperse the high stresses experienced in those areas. Other changes

were made as well, but were not as significant.

The pin-latch mechanism works by having one side of the lid (light gray on the left of Figure

11) held down by something like a reinforced snap-fit joint that doesn't actually flex (dark gray

on the left of Figure 11). The lid is able to hinge on and off of this reinforced snap when the pin

(black on the right of Figure 11) is not present. When the pin is present, it prevents the right side

of the lid from lifting off of the base (dark gray of Figure 11), and therefore it cannot hinge open and disengage from the snap on the left. The pin uses a snap-fit mechanism to hold itself in

place, but this is not a load-bearing snap-fit joint with a high degree of flex required. An image of

a physical test piece using this design can be found as Figure 13 of Appendix C.

With the mechanism to hold the enclosure together figured out, the actual enclosure of the

RFID hardware could finally be designed. The layout was designed by arranging the physical

hardware components on a piece of paper until a compact and efficient layout was found (Figure

14 of Appendix C). The final design for this enclosure can be found as Figure 15 of Appendix C.

The basic design consisted of a base where the electronics would be mounted on (green on

Figure 15), a lid to cover everything up (gray on Figure 15), a riser to hold the RFID module

close to the surface of the lid (blue on Figure 15), and the pins of the pin-latch mechanism

(yellow on Figure 15).

The area of the base (green) was estimated based on how much space the hardware

components took up from the layout in Figure 14 of Appendix C. The base also has holes on it

for mounting to a wall, these were copied from measurements taken of the mounting holes of a

household smoke detector. There is a hole roughly in the middle for the access point

configuration button. There are also the reinforced snaps and the second set of holes for the pins

that came from the test design. Finally, the base has a large protrusion between the two pin holes

for mounting the power jack.

The lid (gray) has the two holes for the pins, along with a bigger hole in the middle for the

power jack to stick out of. There is a hole to the side of the pin holes used for connecting a debug

cable to the ESP32 microcontroller in the event that long term debugging or re-flashing of the

firmware is required. The back of the lid has two slots for each of the snaps to hook into.

The pins (yellow) of the enclosure are the exact same design as used by the test piece. The

riser (blue) for the RFID module is just a slanted flat surface (to give the crystal oscillator some

space under the lid) with legs that have a little extra material at the bottom for gluing to the base.

Figure 16 of Appendix C shows the RFID node with the assembled electronics within.

Everything was secured using hot-melt glue and all connections were soldered. As can be seen,

there was extra space in the enclosure due to the fact that the components were able to be packed

tighter than anticipated because of the three-dimensional arrangement. Figure 17 shows the

completed RFID node powered on with the blue status light in the bottom right side and the two

power indicators showing through the somewhat translucent lid of the enclosure.

## Database

Since the hardware is not designed to be a standalone product, a server is needed to process

and handle the data generated by the RFID nodes. Since that data is also useless unless it can be

accessed and manipulated, a front end to the server is required as well. Even before the server,

the data generated by the users needs to be stored somewhere, so a database is needed. As

mentioned in a previous chapter, the MySQL database was chosen due to its reliability and

ubiquity.

Figure 18 of Appendix C shows the different tables that were used to store and organize the

data generated by the users. The table userdb is used to store information about the users such as

their name, email, password for the system, RFID serial number, and other minor information

about them. The table projdb is used to store the available projects that can be worked on,

specifically the title of the project, a description of it, and whether or not it is currently active

(can actually be worked on or is there for historical purposes). The table scannerdb holds the

RFID nodes that have been registered and are allowed to interact with the server; this

information is the node’s unique identifier, the name of the node, and the location that the node is

installed in.

As for tables that store and relate data, there is the rfiddb table which holds the events

generated by the RFID nodes; this table holds the id of the user who clocked in, the id of the

scanner that created this event, along with what day and time the event occurred. The daydb table

holds the “clock in, clock out” records for the days for each user; it stores the id of the user who

clocked in/out, the day that the record describes, when the shift started, when the shift ended, and

how many hours the user worked that day. The workdb table stores each thing that the user

worked on for each day; specifically it stores the id of the user, the id of the record of the day

when the work happened, the id of the project that this work relates to, a description of the work

done, when the work started, and when the work ended.

To access the data in the database, standard SQL queries were used such as SELECT,

INSERT, and UPDATE. All database access is done by the server, along with the generation of

any SQL queries. A complete listing of the SQL queries used in the server can be found in Table

1 of Appendix B. If more than one query is used in an API call, then the query will be numbered.

Options wrapped in curly braces ({}) and separated by slashes (/) indicate that the query may be

generated using any one of those options. Parts of the queries wrapped in square brackets ([])

indicate that the part may or may not be used in the generation of the query depending on what

flags were given to generate the query. Question marks (?) indicate where data is inserted into

the query before sending it to the database for evaluation.

## Server Software

Server software is needed to connect the database to the user interface. As mentioned in a

previous section, the Node.js framework is used to run the logic needed to provide that

connection. The role of the server is quite simple; the server has to be able to serve web pages to

the users, accept API calls and return the relevant data, and interact with the database to fulfill

the API calls. Of course, this is easier said than done. Because of this, the use of third party

libraries was warranted to ease the development effort. A total of eight libraries were used:

express for serving web pages and handling GET/POST requests, body-parser for decoding

POST query parameters, client-sessions for maintaining session cookies to store login

information, fs for accessing files on the server’s file system, mysql for providing a software

interface to the MySQL database, crypto for generating random numbers for use in password

salts, cron for executing jobs at scheduled times, and multer for handling files uploaded through

POST requests.

The server begins to set itself up by configuring the multer library to store files in the public/

userpics/ directory, but only if the files are less than 10MB and end with one of the following

extensions: png, jpg, jpeg, gif. Then it specifies the public folder as the directory to look for a file

to serve up when an unknown GET request is made. Then it uses the db.key file to configure a

connection to the MySQL database with the mysql library. The db.key file is a JSON encoded file

that contains the following properties: hostsite (the URL of the MySQL server), database (the

name of the database), username (the username to the database account), password (the password

of the database account). Afterwards, the server uses the cron library to create a cron job that

runs every midnight to clock out any accounts that weren’t clocked out for the day. This cron job

uses the SQL queries in Table 1 of Appendix B to read all the clock-in records for the day

(cron_job(1)), read all RFID events (cron_job(2)), then see if any clock-out events were

generated and update the clock-out records accordingly (cron_job(3)). Then the server creates an

interrupt handler that waits for the SIGINT signal and uses that to stop all cron jobs, close the

database connection, and stop the server. The server then applies the configuration for session

cookies that have a 7 day duration whose 7 day limit resets on any activity by a user. Then the

server configures a request to the root URL to go to the clock-in page if a user is logged in, or to

the login page otherwise.

Then some helper functions are defined for use in the API sections of the code. The first

function returns a boolean value if the user making a request is currently logged in or not. The

second function is a simple wrapper for the functions in the mysql library needed to send an SQL

query to the database and receive a response; this function takes care of error states as well. The

third function is for the purpose of logging incidents on the server, such as an unauthorized user

trying to call an API function which requires administrator privileges; the incidents are viewed in

the user interface.

Then a special lookup table is created for the purpose of letting the account API know when

a user’s data cache has become outdated and must be refreshed from their entry in the database.

The account API is then set up to be accessed by sending a POST request to the /account

URL with the required parameters embedded in the POST request. It is not possible to call the

API or send over parameters using a GET request because it was thought to be less secure to

send user information over a GET request because less work is required to intercept the data in a

GET request. With the exception of the call to log in, all account API calls require the user to be

logged in.

The following are the API calls available in the account API. Table 2 of Appendix B shows

the parameters for the API call; all parameters must be send through a POST request. The login

call uses the login query from Table 1 of Appendix B to see if a user with the specified email

exists, if so then it hashes the provided password and sees if it matches the hash in the database,

if so then it creates a persistent session for the user. The logout call redirects the user to

the /account/logout.html page where the persistent session is terminated. The getuser call uses

the getuser query of Table 1 of Appendix B to retrieve data about a user, admins can retrieve data

for users other than themselves. The data that is returned is stripped of the hash and salt, along

with having the estimated times parsed from JSON. This call also updates the user cache if the

user is marked in the special lookup table because the cache is outdated.

The following account API calls serve for modifying user records, refer to Table 2 of

Appendix B for more details. The newuser call uses the newuser SQL query in Table 1 to insert a

minimal user record into the users table, afterwards returning the id of the new record so that the

fields may be filled out. The edituser call updates properties on a user’s record (admin users can

edit the records of users other than themselves) and marks the user cache to be updated for this

user. This call uses the edituser(1) SQL query of Table 1 to update a password using the crypto

library if that is the field to edit, the edituser(2) query is used to update the picture of the user,

and the edituser(3) query is used to modify any of the other user properties. The deleteuser call

uses the deleteuser SQL query to delete the record of a user, it also updates the user cache for

this user so the system will be rendered unusable for a deleted user. The updateestim API call

edits the daily estimations of a user (admins can edit those of other users) which are stored as the

JSON encoded times a user typically starts work on a certain weekday and how many hours the

shift usually lasts. The updateestim(1) SQL query is used to write the updated JSON data back to the user record, or if an admin is updating this data for another user, then the updateestim(2)

query is used to read the JSON string before making modifications and sending it back to the

database. This function also marks the user’s cache to be updated.

After the accounts API is set up, some extra GET request handlers for the accounts are set

up. These GET request handlers are specifically to redirect to other accounts pages or actually

serve up the files for the requested pages. A GET request to the /account URL either redirects the

user to the user profile page, or to the login page. A request to the /account/logout URL

terminates the user’s session and redirects the user to the login page. A request to the

/account/login.html URL will either serve up the login.html file or redirect the user to the

/account/user.html if they’re already logged in. A request to /account/user.html either serves up

the user.html file or redirects the user back to /account/login.html if they’re not logged in.

After all the setup for the account portion of the server is finished, the server proceeds by

setting up a cache for unknown RFID events that arrive to the server. This cache stores the day

and time that the event was received along with the id of the RFID card that was scanned and the

id of the RFID node that submitted the event.

Then the server proceeds with setting up the general API calls for use by the UI. The server

listens for GET or POST requests to the /api URL and merges any POST parameters with the

GET parameters; it is still possible to access the original POST data for API calls that require

POST-only parameters, but the original GET data is not preserved and can be overwritten by

POST parameters with the same key name. The parameters are then sent on to a function whose

job it is to process the general API calls and handle permissions. If a non-admin user tries to

access an API call that is admin-only or the admin-specific features of an API call, then that user is reported to the incident log mentioned above. Table 3 of Appendix B shows the available API

calls, their parameters, and whether the call or any parameters are for admin usage only.

Only two of the API calls are available without having to be logged into the server, the

rfidevent call and the gettime call. The rfidevent call uses the rfidevent(1) SQL query of Table 1

in Appendix B to see if the scanner sending the request is registered with the system, if not then

it adds a record to the unknown RFID cache. If it is a registered node, then it uses the

rfidevent(2) query to see if a user is associated with the id of the RFID card, if not then it adds a

record to the unknown RFID cache. If the card is registered to a user, then the rfidevent(3) SQL

query is used to log the RFID event to the database, the server uses rfidevent(4) to check if the

user has been clocked in for the day, and if not, then the server uses rfidevent(5) to clock the user

in for the day. The gettime API call just returns the UNIX time in seconds for the purpose of

synchronizing the clocks on the RFID nodes.

The rest of the API calls require the user to be logged in to use them. The getclocks call uses

the getclocks SQL query to return the clock in/out records for a user with optional filter to select

which records to return. This call also has the admin-only feature that allows for returning the

clock in/out records of other users. The addclocks call uses the addclocks SQL query to allow a

user to clock in for the day using the web interface instead of scanning their RFID card. The

editclocks call uses the editclocks(2) query to allow a user to change the hours that they worked

for a day, or it uses editclocks(1) to allow other properties to change while automatically

updating the hours that they worked if they change the time they started or ended their shift; this

call allows an admin to edit the clock in/out records of other users.

The getworks API call uses the getworks SQL query to return the work descriptions of a user

with optional filters to control which work descriptions are returned; this call allows an admin to view the work descriptions of other users. The addworks call uses the addworks query to allow a

user to enter a work description for the project they’re working on. The editworks call uses the

editworks query to allow a user to edit various properties of a specified work description; this

call also allows admins to modify the properties of another user’s work descriptions.

The getprojs API call uses the getprojs(2) SQL query to return all the projects that have been

registered with the system, or it uses the getprojs(1) query to return all the projects without their

descriptions; there is an optional filter to only show projects that are still active. The addprojs

call is an admin-only call that uses the addprojs SQL query to register a project with the system.

The editprojs call is an admin-only call that uses the editprojs SQL query to update a property of

a project record.

The getscanners API call is an admin-only call that gets a list of registered RFID nodes

using the getscanners(2) SQL query, or getscanners(1) query if location text isn’t needed. The

addscanners call is an admin-only call that registers an RFID scanner with the system using the

addscanners SQL query. The editscanners call is an admin-only API call that uses the

editscanners query to edit a property of a specified RFID node registration record.

The gethours API call returns the times that a user worked for a given span of days using the

gethours(2) SQL query. An admin has the ability to return the hours worked by another user, or

by all users for a given span of days using the gethours(1) query. The getemployees call is an

admin-only command that returns the records for all employees with password and RFID data

stripped out; this call uses the getemployees SQL query.

The getrfidevents API call is an admin-only call that returns the RFID event records using

optional filters for day spans and users, this call uses the getrfidevents query. The

geturegrfidevents call is an admin-only call that returns the cache of unknown RFID events. The getincidents call is an admin-only call that return the log of attempted unauthorized API access

showing which API call was called and which user attempted it.

Finally, once the server is set up and ready to begin accepting HTTP GET/POST requests,

then a function is called to start the server and have it listen on port 8080.
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

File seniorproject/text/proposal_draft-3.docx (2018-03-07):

# UNIVERSITY OF LA VERNE

# LA VERNE, CALIFORNIA

# Spring 2018

# SENIOR PROJECT PROPOSAL

J2 INNOVATIONS’ AUTOMATIC RFID EMPLOYEE CLOCKING SYSTEM

# A SENIOR PROJECT SUBMITTED TO:

# THE FACULTY OF

# COMPUTER SCIENCE AND COMPUTER ENGINEERING

# IN CANDIDANCY FOR THE DEGREE OF

# BACHELORS OF SCIENCE

# SOFTWARE / ENGINEERING

# BY

# KOPPANY HORVATH

Table of Contents

# 1 Personal background

My name is Koppany Horvath, my major is Computer Science and Computer Engineering at the University of La Verne with concentrations in Software and Engineering. I originally got interested in computer science when I got my first computer at age 14 and wanted to know more after I wrote my first couple hundred programs. I have gotten to the point where most aspects of my life are based on computer science, such as my job and my hobbies. My other hobbies involve electronics, robotics, retro-computing, and watching Star Trek. My current job is as a programmer at J2 Innovations, but prior to that, I was a kitchen knife salesperson.

# 2 Introduction

Keeping accurate records of employee work times is very important. Not only does it ensure that the employees get paid for what they worked, but it also makes sure that conflicts arising from accidental overpaying or underpaying do not occur. Accurate time records also allow for the possibility of measuring work performance when coupled with descriptions of what was done during those hours. Using this information to modify the working environment and schedules can lead to higher productivity in a company.

# 3 Organizational overview

The target company for the senior project is J2 Innovations. J2 Innovations is a small software company that was founded by Jason Briggs in 2009 and current has about 20 people working for it. This company specializes in building automation software. The types of automation have to do with controlling HVAC systems and lighting. The software produced at J2 Innovations also records sensors scattered throughout buildings to monitor parameters such as room temperatures or whether the lights are on or off. J2 Innovations has partnerships with companies such as KMC Controls and Siemens. The company has one office in Chino, California, and one office in District 5 of Bucharest, Romania, along with a few remote employees scattered around the world. This project will be made for and deployed in the Chino office.

# 4 Problem statement

The current system has a few problems that tend to bother the people working at J2 Innovations. The problems are listed below in descending order of severity.

1. The biggest problem that the manager complains about is that the system is a third party service that requires monthly payment which is increased for each new employee using the system, and as such it is also not flexible in terms of adding new features.
2. A problem that the employees don’t like is that with the current system employees have to manually type in their starting time and ending time which sometimes results in inaccurate information when an employee can't remember their starting time accurately or decides to report incorrect times.
3. Something that the project manager is annoyed about is that he has no idea what the general schedule is for part time employees who have very dynamic schedules, and the current system has no fast way to see what an employee’s usual schedule is.
4. Another minor problem that employees don’t like is that they are required to submit a daily email containing their work for the day along with a weekly email containing not only the information from the daily emails, but what their times were for each day that they worked. This is very redundant and a better system would allow the project manager to have a less clouded inbox so as to focus on customer emails.
5. One problem that frustrates employees sometimes is that the current system is sometimes difficult to use and does not always act the way it is expected to act. An example of this is when entering in the ending time, the system attempts to guess if the time is AM or PM and sometimes gets it wrong, leading to the employee time being too much or too little if they don’t spot this error and correct it.

# 5 Scope of the project

The proposed project will utilize both custom made software and custom made hardware to solve the problems detailed above. Specifically, this project will result in the construction of the Radio Frequency Identification (RFID) hardware capable of recording user input events. This project will also result in the development of the software needed to record the input events from the RFID hardware and provide an interface for the users to view, edit, and describe the input events. The software interface will also allow the management position to view the information of employees in order to calculate their hours and paychecks.

# 6 Description of the current system

The current system used for J2 Innovations’ employee clocking system is a third party service called Toggl. This is an online time tracking system for small businesses and can be found at https://toggl.com and is available from $9 per person per month to $49 per person per month. Being web based, it is accessed through a web browser and has no associated hardware with it.

The way an employee uses the system at J2 Innovations is they are invited to join by the manager via an e-mail link. Once they sign up from the link, they then have an account on Toggl that they can use to log their hours and the work that they did.

With that account, an employee can enter their starting time at the beginning of their shift. During their shift, the employee uses the text input field to type in the various activities that they did throughout their shift. At the end of their shift, the employee enters in their ending time and submits all that information to the Toggl server.

Alternatively, due to limitations of the system, a user may record all of this information locally in a text file, and then enter in and submit that information at the end of their shift.
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

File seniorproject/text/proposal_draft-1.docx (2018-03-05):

# UNIVERSITY OF LA VERNE

# LA VERNE, CALIFORNIA

# Spring 2018

# SENIOR PROJECT PROPOSAL

J2 INNOVATIONS’ AUTOMATIC RFID EMPLOYEE CLOCKING SYSTEM

# A SENIOR PROJECT SUBMITTED TO:

# THE FACULTY OF

# COMPUTER SCIENCE AND COMPUTER ENGINEERING

# IN CANDIDANCY FOR THE DEGREE OF

# BACHELORS OF SCIENCE

# SOFTWARE / ENGINEERING

# BY

# KOPPANY HORVATH

Table of Contents

# 1 Personal background

My name is Koppany Horvath, my major is Computer Science and Computer Engineering at the University of La Verne with concentrations in Software and Engineering. I originally got interested in computer science when I got my first computer at age 14 and wanted to know more after I wrote my first couple hundred programs. I have gotten to the point where most aspects of my life are based on computer science, such as my job and my hobbies. My other hobbies involve electronics, robotics, retro-computing, and watching Star Trek. My current job is as a programmer at J2 Innovations, but prior to that, I was a kitchen knife salesperson.

# 2 Introduction

This proposal is about the solution to the problem of efficient time clocking to keep track of the hours worked by employees of the company J2 Innovations.

//emphasize the importance of time clocking

//don’t mention proposal here

# 3 Organizational overview
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

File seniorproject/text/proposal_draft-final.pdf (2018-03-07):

UNIVERSITY OF LA VERNE
LA VERNE, CALIFORNIA
Spring 2018

SENIOR PROJECT PROPOSAL

J2 INNOVATIONS’ AUTOMATIC RFID EMPLOYEE CLOCKING SYSTEM

A SENIOR PROJECT SUBMITTED TO: THE FACULTY OF
COMPUTER SCIENCE AND COMPUTER ENGINEERING IN CANDIDANCY FOR THE DEGREE OF BACHELORS OF SCIENCE
SOFTWARE / ENGINEERING

BY
KOPPANY HORVATH

### Table of Contents

J2 INNOVATIONS’ AUTOMATIC RFID EMPLOYEE CLOCKING SYSTEM | Page 1 of 8
Koppany Horvath | 3/5/2018
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

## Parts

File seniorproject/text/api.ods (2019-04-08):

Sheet: Sheet1
action | admin | user | anyone | params (*?post) | description
login |  |  | y | () (email*, passw*) | logs the user in using a persistent session
getuser | y | y |  | (?uid*) () | returns a user's session data
updateestim | y | y |  | (?uid*) (tag*, value*, day*) | updates a user's estimated times table
edituser | y | y |  | (?uid*) (tag*, value*) | edits a user's account data
newuser | y |  |  | () () | creates a new user and returns the id
deleteuser | y |  |  | (uid*) () | deletes a user's account
logout |  |  | y | () () | logs a user out of their persistent session
rfidevent |  |  | y | () (time*, id*, node*) | uses the RFID event from a node to update the event database and clock a user in if applicable
gettime |  |  | y | () () | returns the current unix time of the server
getclocks | y | y |  | (?uid) (?date, ?week, ?fromday?, ?today, ?notjustnull) | returns past/current clock in/out records of a user
addclocks |  | y |  | () (date, time) | adds a clock in record for a user
editclocks | y | y |  | (?uid) (tag, value, did) | edits a clock in/out record for a user
getworks | y | y |  | (?uid) (?did, ?fromdid, ?todid) | returns past/current work description records of a user
addworks |  | y |  | () (did, pid, desc, tstart, tend) | adds a work description record
editworks | y | y |  | (?uid) (tag, value, wid) | edits a work description record
getprojs |  | y |  | () (?nodesc, ?active) | returns available project categories
addprojs | y |  |  | (title, desc, ?active) () | adds a project category
editprojs | y |  |  | (tag, value, pid) () | edits a project category
gethours | y | y |  | (?allemployees, ?uid) (?fromday, ?today) | returns the amount of hours worked by one or multiple users for a given time span
getemployees | y |  |  | () () | returns a list of all registered users
getrfidevents | y |  |  | (?uid, ?day, ?fromday, ?today) () | returns records from the RFID event database
geturegrfidevents | y |  |  | () () | returns all RFID records that were not associated with any users
getscanners | y |  |  | (?noloc) () | returns all registered RFID scanners
addscanners | y |  |  | (devid, name, location) () | adds an RFID scanner
editscanners | y |  |  | (tag, value, sid) () | edits an RFID scanner
getincidents | y |  |  | () () | returns all incidents where a non admin user tried to access an admin feature

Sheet: Sheet2
login | anyone, no login needed | logs the user in using a persistent session
 | email | post | the email to log in with
 | passw | post | the password to log in with
getuser | users, admin only features | returns a user's session data
 | uid | post, optional, admin only | the id of the user to get
updateestim | users, admin only features | updates a user's estimated times table
 | uid | post, optional, admin only | the id of the user to update
 | tag | post | which property to update, can be “start” or “hours”
 | value | post | what the value of the indicated property should be
 | day | post | which day's estimate to update
edituser | users, admin only features | edits a user's account data
 | uid | post, optional, admin only | the id of the user to update
 | tag | post | which property to update, can be “email” or “fname” or “lname” or “admin” or “wage” or “picture” or “rfid” or “passwd”
 | value | post | what the value of the indicated property should be
newuser | admin only | creates a new user and returns the id
deleteuser | admin only | deletes a user's account
 | uid | post, admin only | the id of the user to delete
logout | anyone, no login needed | logs a user out of their persistent session
rfidevent | anyone, no login needed | uses the RFID event from a node to update the event database and clock a user in if applicable
 | time | post | the time that the RFID event was recorded at the node
 | id | post | the id of the RFID card that was recorded
 | node | post | which node the recorded event happened at
gettime | anyone, no login needed | returns the current unix time of the server
getclocks | users, admin only features | returns past/current clock in/out records of a user
 | uid | optional, admin only | the id of the user to get data of
 | date | optional | specify the date of the records to be returned, overrules week parameter
 | week | optional | specify the week of the records to be returned, overrules fromday and today parameters
 | fromday | optional | specify the starting date of records to be returned
 | today | optional | specify the ending date of records to be returned
 | notjustnull | optional | also return records that are clocked out
addclocks | users | adds a clock in record for a user
 | date |  | the date that the clock in record should use
 | time |  | the time that the user clocked in at
editclocks | users, admin only features | edits a clock in/out record for a user
 | uid | optional, admin only | the id of the user to edit the records of
 | tag |  | which property to edit, can be “day” or “tstart” or “tend”
 | value |  | what the value of the indicated property should be
 | did |  | the id of the clock record that will be updated
getworks | users, admin only features | returns past/current work description records of a user
 | uid | optional, admin only | the id of the user to return the records of
 | did | optional | specify the id of the clock record that these records belong to, overrules fromdid and todid parameters
 | fromdid | optional | specify the id of the beginning clock record that the records belong to
 | todid | optional | specify the id of the ending clock record that the records belong to
addworks | users | adds a work description record
 | did |  | the id of the clock record that this work description belongs to
 | pid |  | the id of the project record that this work description is associated with
 | desc |  | the description of the work description
 | tstart |  | the starting time of this work description
 | tend |  | the ending time of this work description
editworks | users, admin only features | edits a work description record
 | uid | optional, admin only | the id of the user that this work description belongs to
 | tag |  | which property to edit, can be “tstart” or “tend” or “pid” or “description”
 | value |  | what the value of the indicated property should be
 | wid |  | the id of the work record to be updated
getprojs | users | returns available project categories
 | nodesc | optional | return the project records with everything except descriptions
 | active | optional | specify to only return active projects
addprojs | admin only | adds a project category
 | title |  | the title of the project
 | desc |  | a description of the project
 | active | optional | whether or not the project should start out active
editprojs | admin only | edits a project category
 | tag |  | which property to edit, can be “title” or “description” or “active”
 | value |  | what the value of the indicated property should be
 | pid |  | the id of the project record to be updated
gethours | users, admin only features | returns the amount of hours worked by one or multiple users for a given time span
 | allemployees | optional, admin only | specify that the calculation should happen for all users
 | uid | optional, admin only | specify that the calculation should happen for one specifc user, requires allemployees to be defined
 | fromday | optional | specify the start of the time span to calculate
 | today | optional | specify the end of the time span to calculate
getemployees | admin only | returns a list of all registered users
getrfidevents | admin only | returns records from the RFID event database
 | uid | optional | the id of the user to get the RFID events of
 | day | optional | which date to get the RFID events of, overrules fromday and today parameters
 | fromday | optional | the starting date to get the RFID events of
 | today | optional | the ending date to get the RFID events of
geturegrfidevents | admin only | returns all RFID records that were not associated with any users
getscanners | admin only | returns all registered RFID scanners
 | noloc | optional | return everything but the location property
addscanners | admin only | adds an RFID scanner
 | devid |  | the hardware id of the scanner to add
 | name |  | the name of the scanner to add
 | location |  | the location of the scanner to add
editscanners | admin only | edits an RFID scanner
 | tag |  | which property to edit, can be “devid” or “name” or “location”
 | value |  | what the value of the indicated property should be
 | sid |  | the id of the scanner record to update
getincidents | admin only | returns all incidents where a non admin user tried to access an admin feature

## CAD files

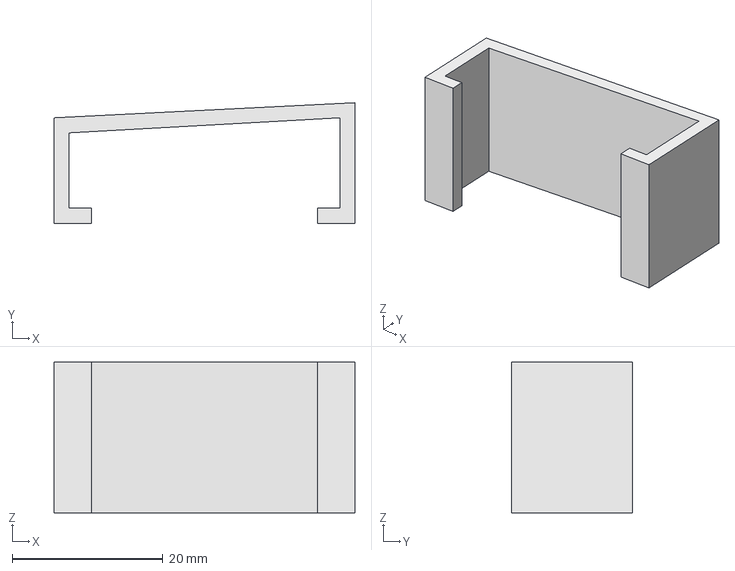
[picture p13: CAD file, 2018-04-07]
rfidhardware/stand.fcstd
39.9 x 16.0 x 20.0 mm

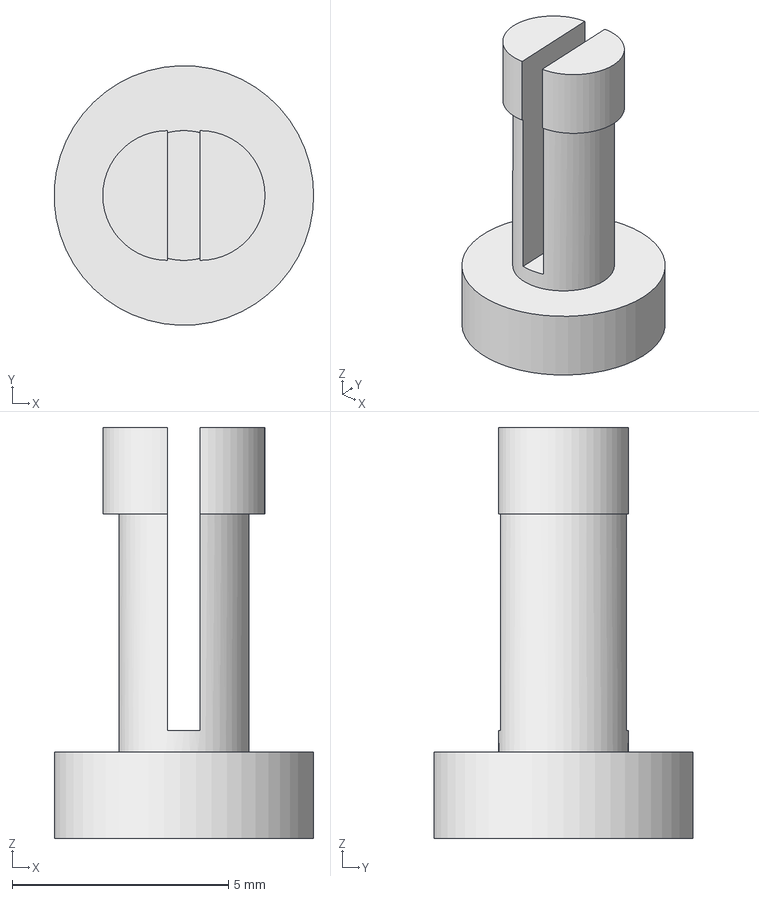
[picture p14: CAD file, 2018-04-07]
seniorproject/rfidfirmware/pin.fcstd
5.99 x 6.00 x 9.50 mm

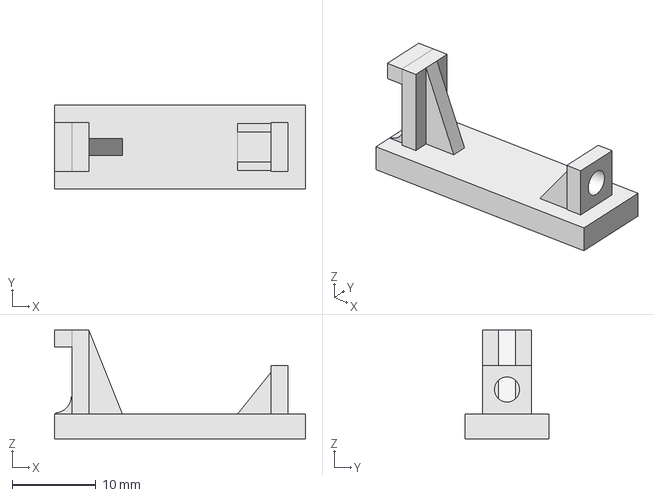
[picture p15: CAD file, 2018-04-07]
seniorproject/tests/casebottom2.fcstd
30.0 x 10.0 x 13.0 mm

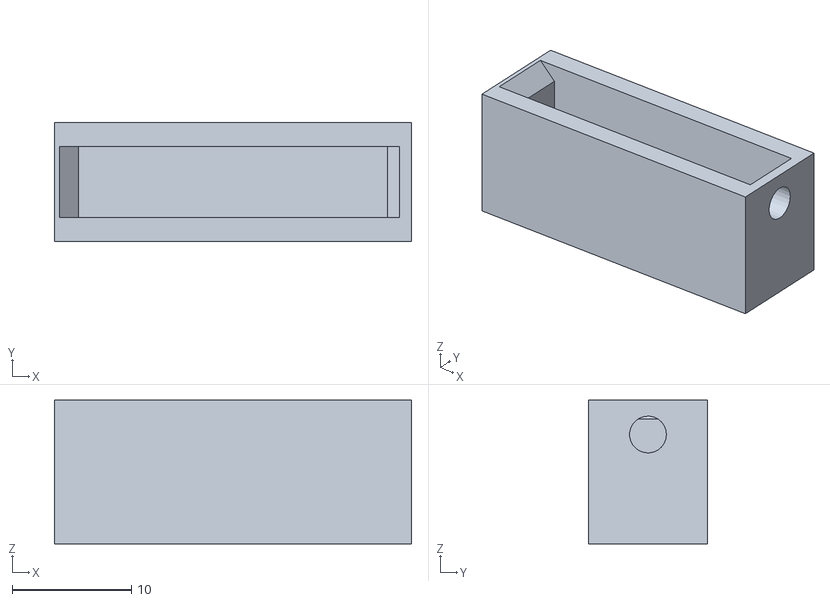
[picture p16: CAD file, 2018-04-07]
seniorproject/tests/casefinal/casetop.stl
30.0 x 10.0 x 12.1

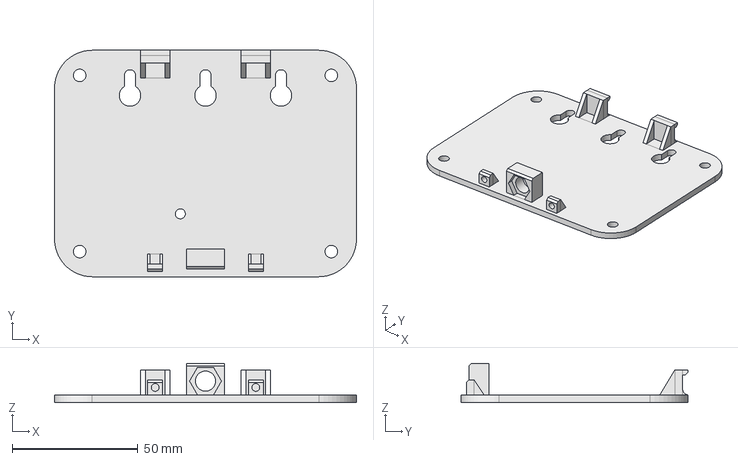
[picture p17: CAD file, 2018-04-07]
rfidhardware/case.fcstd
120.0 x 90.0 x 15.5 mm

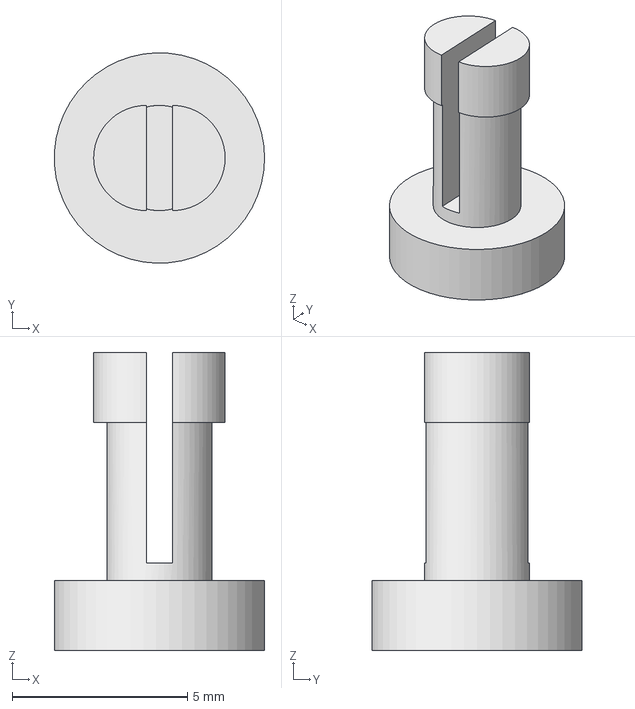
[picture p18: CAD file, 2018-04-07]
seniorproject/tests/casepin.fcstd
5.99 x 6.00 x 8.50 mm

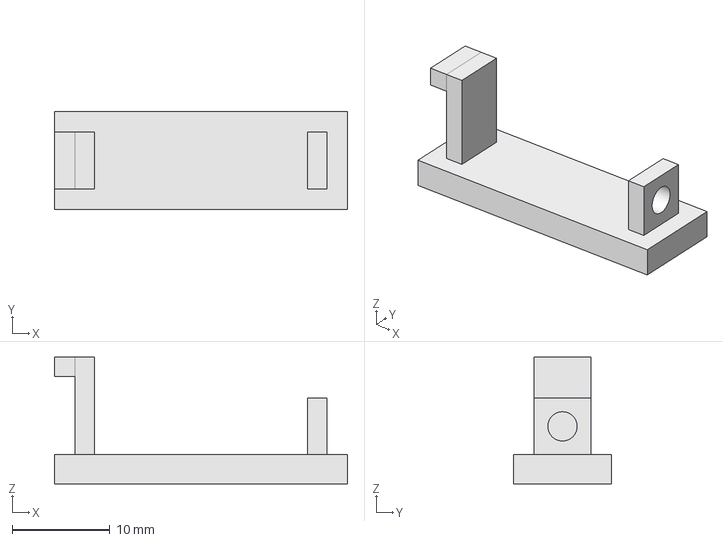
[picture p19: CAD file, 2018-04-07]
seniorproject/tests/casebottom.fcstd
30.0 x 10.0 x 13.0 mm

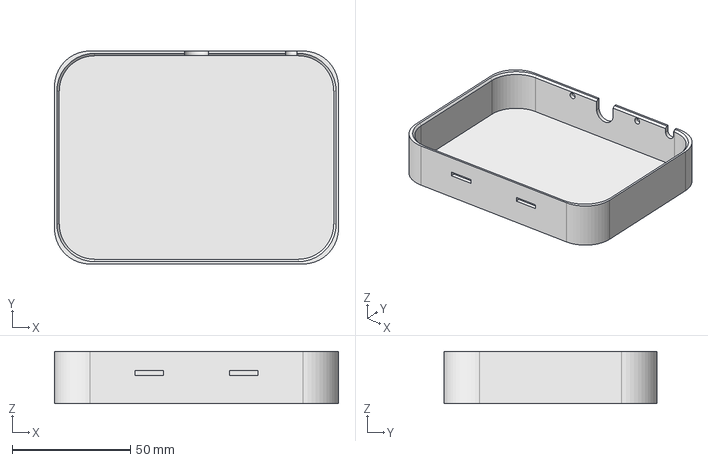
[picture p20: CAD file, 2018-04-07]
rfidhardware/lid.fcstd
120.0 x 90.0 x 22.0 mm

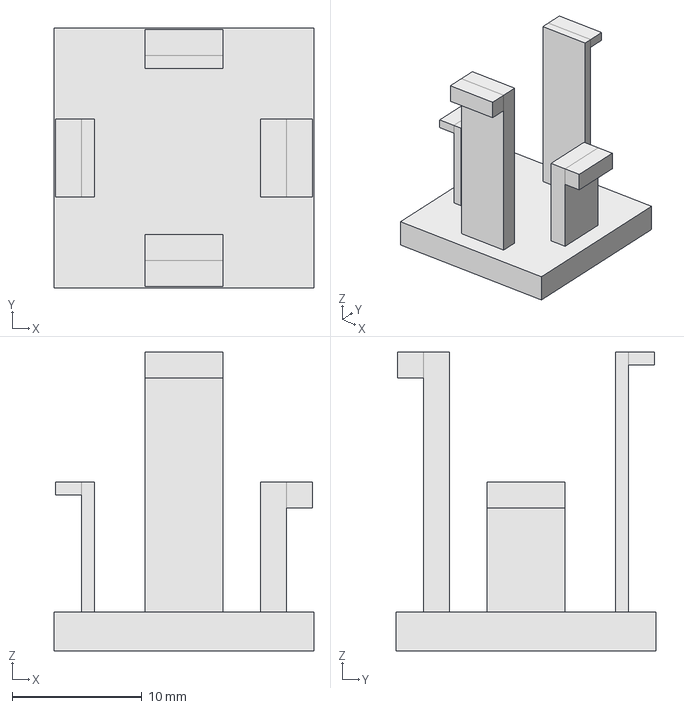
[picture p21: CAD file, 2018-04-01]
seniorproject/tests/snaps.fcstd
20.0 x 20.0 x 23.0 mm

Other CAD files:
seniorproject/tests/casefinal/casetop2.fcstd
seniorproject/tests/casefinal/casebottom.stl
seniorproject/tests/casetop.fcstd
seniorproject/tests/casefinal/casebottom3.fcstd
rfidhardware/case.stl
rfidhardware/lid.stl
rfidhardware/pin.stl
rfidhardware/stand.stl
seniorproject/rfidfirmware/case.stl
seniorproject/rfidfirmware/lid.stl
seniorproject/rfidfirmware/pin.stl
seniorproject/rfidfirmware/stand.stl
seniorproject/tests/casebottom.stl
seniorproject/tests/casebottom2.stl
seniorproject/tests/casefinal/casepin.stl
seniorproject/tests/casepin.stl
seniorproject/tests/casetop.stl
seniorproject/tests/snap2.fcstd
seniorproject/tests/snaplid.fcstd
seniorproject/tests/snaplid.stl
seniorproject/tests/snaplid2.fcstd
seniorproject/tests/snaplid2.stl
seniorproject/tests/snaps.stl
seniorproject/tests/snaps2.stl

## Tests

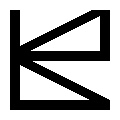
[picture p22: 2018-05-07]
seniorproject/tests/Untitled.png

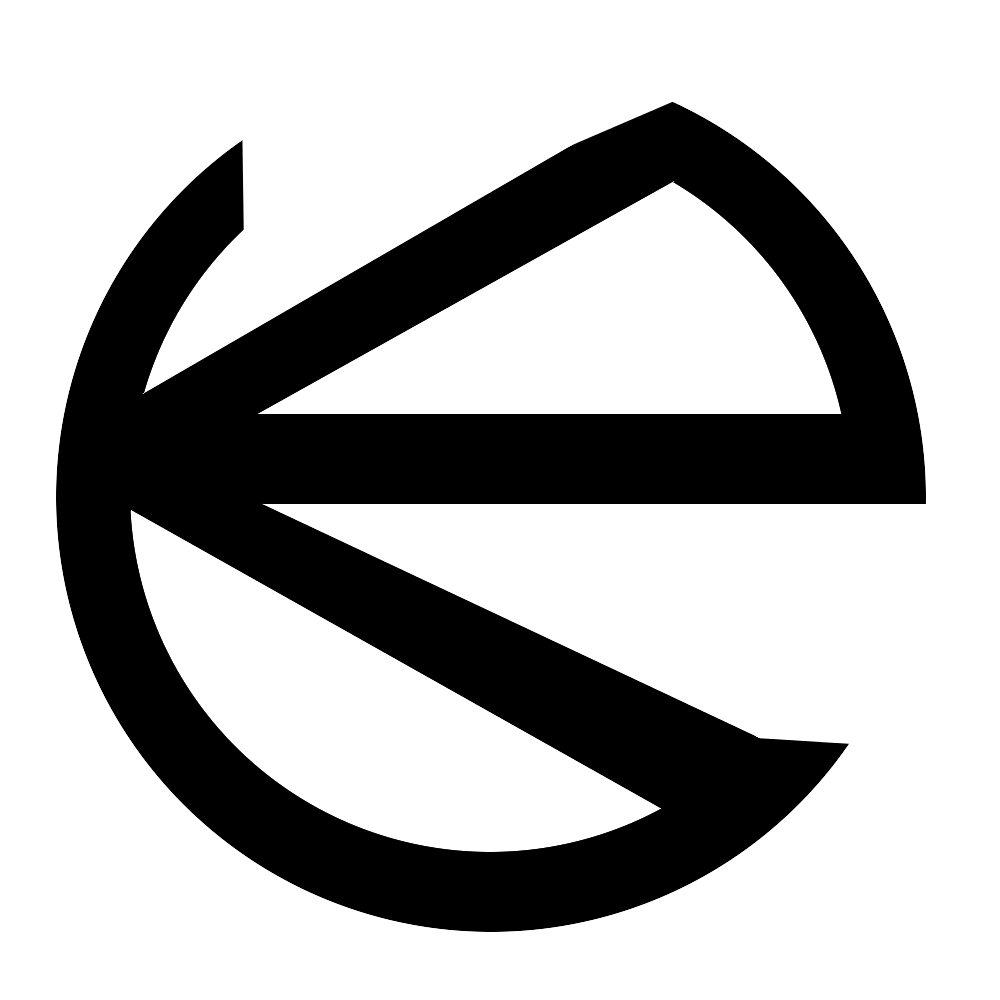
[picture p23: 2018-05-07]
seniorproject/tests/Titled2.png

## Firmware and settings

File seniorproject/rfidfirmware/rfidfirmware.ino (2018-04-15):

/*
 * RFID Node Firmware @copy Koppany Horvath 2018
 * This is the firmware that goes into the RFID nodes
 * for the ARECS project.
 * All code is under the MIT license and comes as is.
 * I assume no responsibility for anything relating to
 * this code.
 */

#include <WiFi.h>
#include <SPI.h>
#include <MFRC522.h>
#include <FS.h>
#include <AsyncTCP.h>          //https://github.com/me-no-dev/AsyncTCP
#include <ESPAsyncWebServer.h> //https://github.com/me-no-dev/ESPAsyncWebServer
#include <DNSServer.h>
#include <Preferences.h>
#include "rfidevent.h"

//hardware pin config
const int statLed = 2;
const int tone1 = 15;
const int tone2 = 4;
const int RST_PIN = 22;
const int SDA_PIN = 5;
const int configPin = 25; //button to enable config ap mode
const int apIdPins[4] = {32, 33, 34, 35}; //least significant to most

//wifi config
String ssid = "asdfasdf";
String pass = "asdfasdf";

//service config
String site = "192.168.1.123";
uint16_t port = 1234;
String siteport = "192.168.1.123:1234";

//time variables
uint64_t setTime = 0;
uint64_t servTime = 0;
bool timeWasInit = false;

//other stuff
AsyncWebServer server(80);
DNSServer dnsServer;
Preferences configs;
MFRC522 mfrc522(SDA_PIN, RST_PIN);
const char hexcodes[16] = {'0','1','2','3','4',
  '5','6','7','8','9','A','B','C','D','E','F'};
bool isConfig = false;
int counter = 0;
bool ledOn = false;

//rfid buffer/queue
RFIDEvent rfidbuff[256];
int buffread = 0;
int buffwrite = 0;

//configuration page html
const char index_html1[] PROGMEM =
  "<!DOCTYPE HTML>\n"
  "<html>\n"
  "  <head>\n"
  "    <title>ARECS Configuration</title>\n"
  "    <meta charset=\"utf-8\">\n"
  "    <meta name=\"viewport\" content=\"width=device-width, initial-scale=1.0\">\n"
  "  </head>\n"
  "  <body>\n"
  "  <b>ARECS Configuration Page</b><br><br>\n"
  "  Node Identifier: ";
char uuid[13];
const char index_html2[] PROGMEM =
  "<br><br>\n"
  "  <form action=\"/configure\" method=\"POST\">\n"
  "    Select Wifi Network<br>\n"
  "    <select id=\"ssids\" name=\"ssid\">\n"
  "      <option value=\"SSID 1\">Loading SSIDS...</option>\n"
  "    </select><br><br>\n"
  "    Type in WiFi Password<br>\n"
  "    <input type=\"password\" name=\"pass\"><br>\n"
  "    Confirm WiFi Password<br>\n"
  "    <input type=\"password\" name=\"ssap\"><br><br>\n"
  /*"    TCP/IP Settings<br>\n"
  "    Static IP<br>\n"
  "    <input type=\"text\" name=\"ip\"><br>\n"
  "    Gateway<br>\n"
  "    <input type=\"text\" name=\"gateway\" value=\"192.168.1.1\"><br>\n"
  "    Subnet Mask<br>\n"
  "    <input type=\"text\" name=\"subnet\" value=\"255.255.255.0\"><br>\n"
  "    Primary DNS<br>\n"
  "    <input type=\"text\" name=\"primary\" value=\"8.8.8.8\"><br>\n"
  "    Secondary DNS<br>\n"
  "    <input type=\"text\" name=\"secondary\" value=\"8.8.4.4\"><br><br>\n"*/
  "    Service Address<br>\n"
  "    <input type=\"text\" name=\"serv\"><br>\n"
  "    Service Port<br>\n"
  "    <input type=\"number\" name=\"port\" value=\"8080\"><br><br>\n"
  "    <input type=\"submit\" value=\"Save Configuration\">\n"
  "  </form>\n"
  "  </body>\n"
  "</html>\n"
  "<script>\n"
  "  function getssids(){\n"
  "    var http = new XMLHttpRequest();\n"
  "    http.open(\"GET\", \"/getssids\", true);\n"
  "    http.onreadystatechange = function(){\n"
  "      if(http.readyState == 4 && http.status == 200){\n"
  "        var ssids = document.getElementById(\"ssids\");\n"
  "        for(var i=ssids.length; i>=0; i--) ssids.remove(i);\n"
  "        http.responseText.split(\":::::\").forEach(function(itm){\n"
  "          var c = document.createElement(\"option\");\n"
  "          c.text = itm;\n"
  "          c.value = itm;\n"
  "          ssids.add(c);\n"
  "        });\n"
  "      }\n"
  "    };\n"
  "    http.send();\n"
  "  }\n"
  "  try{ getssids(); } catch(e){ alert(e); }\n"
  "</script>\n";

//various noises for status
void notify(int m=0){
  if(m == 0){
    beep(500, 200); //success
    beep(1000, 100);
  } else if(m == 1) beep(10000, 100); //node start
  else if(m == 2){
    for(int i=0; i<50; i++){ //failure
      beep(1000, 10);
      delay(10);
    }
  } else if(m == 3){
    beep(1000, 125); //access point activated
    beep(500, 250);
    beep(333, 375);
  }
}

void setup() {
  Serial.begin(115200);
  pinMode(statLed, OUTPUT);
  pinMode(tone1, OUTPUT);
  pinMode(tone2, OUTPUT);
  pinMode(configPin, INPUT);
  for(int i=0; i<4; i++) pinMode(apIdPins[i], INPUT);
  Serial.println();
  Serial.println("ARECS RFID Node V1 by KH-Labs");

  //get hex from dip switch for unique ssid
  uint8_t v = 0;
  for(int i=3; i>=0; i--){
    bool a = digitalRead(apIdPins[i]);
    Serial.print(a);
    Serial.print(" ");
    v <<= 1;
    if(a) v |= 1;
  }
  Serial.print((int)v);
  Serial.print(" ");
  Serial.println(hexcodes[v]);

  //get chip UUID
  uint64_t chipid = ESP.getEfuseMac();
  char uuidtmp[] = "%04X%08X";
  sprintf(uuid, uuidtmp, (uint16_t)(chipid>>32), (uint32_t)chipid);
  uuid[11] = hexcodes[v];

  //check which mode to be in
  configs.begin("wificreds", true);
  isConfig = configs.getBool("isConfig");
  configs.end();

  //let the user know it booted up
  notify(1);

  if(isConfig){
    Serial.println("Mode: AP Config");

    //generate ssid and password based on dip switch
    ssid = "ARECS_Node_";
    ssid += hexcodes[v];
    pass = "password";
    pass += hexcodes[v];
    Serial.print("Starting Config AP: ");
    Serial.print(ssid);
    Serial.print(" / ");
    Serial.println(pass);

    //activate AP mode with generated ssid and password
    WiFi.mode(WIFI_AP);
    WiFi.softAP(ssid.c_str(), pass.c_str());
    delay(1000);
    IPAddress apIP(192, 168, 1, 1);
    WiFi.softAPConfig(apIP, apIP, IPAddress(255, 255, 255, 0));
    Serial.print("IP Addr: ");
    Serial.println(WiFi.softAPIP());

    //serve code for config page
    server.on("/", HTTP_GET, [](AsyncWebServerRequest* request){
      Serial.print("Connection made: ");
      Serial.println(request->url());
      
      AsyncResponseStream* response = request->beginResponseStream("text/html");
      response->print(index_html1);
      response->print(uuid);
      response->print(index_html2);
      
      request->send(response);
    });

    //api call to get available ssids for config form
    server.on("/getssids", HTTP_GET, [](AsyncWebServerRequest* request){
      request->send(200, "text/plain", getSSID());
    });

    //api call to apply settings from config form
    server.on("/configure", HTTP_POST, [](AsyncWebServerRequest* request){
      bool failure = false;
      configs.begin("wificreds", false);

      //apply wifi settings, skip if both passwords are blank
      if(request->hasParam("ssid", true) && request->hasParam("pass", true) && request->hasParam("ssap", true)){
        AsyncWebParameter* p;
        AsyncWebParameter* q;
        p = request->getParam("pass", true);
        q = request->getParam("ssap", true);
        if(p->value() == "" && p->value() == "") Serial.println("Skip WiFi Settings");
        else{
          if(p->value() == q->value()){
            AsyncWebParameter* r = request->getParam("ssid", true);
            configs.putString("ssid", r->value());
            configs.putString("pass", p->value());
          } else{
            Serial.println("Passwords not matching");
            failure = true;
          }
        }
      }

      //apply dhcp settings
      if(request->hasParam("ip",true) && request->hasParam("gateway",true) && request->hasParam("subnet",true)
        && request->hasParam("primary",true) && request->hasParam("secondary",true)){
        AsyncWebParameter* u = request->getParam("ip", true);
        if(u->value() != ""){
          AsyncWebParameter* v = request->getParam("gateway", true);
          AsyncWebParameter* w = request->getParam("subnet", true);
          AsyncWebParameter* x = request->getParam("primary", true);
          AsyncWebParameter* y = request->getParam("secondary", true);
          configs.putString("ip", u->value());
          configs.putString("gateway", v->value());
          configs.putString("subnet", w->value());
          configs.putString("primary", x->value());
          configs.putString("secondary", y->value());
        } else{
          configs.putString("ip", "");
          Serial.println("Skip DHCP Settings");
        }
      }

      //apply service settings, skip if address is blank
      if(request->hasParam("serv", true) && request->hasParam("port", true)){
          AsyncWebParameter* s = request->getParam("serv", true);
          if(s->value() != ""){
            AsyncWebParameter* t = request->getParam("port", true);
            configs.putString("server", s->value());
            configs.putUShort("port", (uint16_t)(t->value().toInt()));
          } else Serial.println("Skip Server Settings");
      }

      //disable access point config mode
      if(!failure) configs.putBool("isConfig", false);
      
      configs.end();

      if(failure) request->redirect("/");
      else request->send(200, "text/html",
        "<meta charset=\"utf-8\">\n"
        "<meta name=\"viewport\" content=\"width=device-width, initial-scale=1.0\">\n"
        "<a href=\"/restart\">Restart to apply changes</a>\n"
      );
    });

    //api call to restart the node to use the settings
    server.on("/restart", HTTP_GET, [](AsyncWebServerRequest* request){
      request->send(200, "text/html", "<h1>Goodbye</h1>");
      Serial.println("Restarting...");
      ESP.restart();
    });

    //go to config form if the url is random
    server.onNotFound([](AsyncWebServerRequest* request){ request->redirect("/"); });

    //start http and dns servers
    dnsServer.start(53, "*", apIP);
    server.begin();

    //let the user know that the access point is ready
    notify(3);
  }
  /////////////////////////////////////////////////////////////
  else{
    Serial.println("Mode: Node");

    //init the rfid reader
    SPI.begin();
    mfrc522.PCD_Init();

    //get the saved settings for wifi and service
    configs.begin("wificreds", false);
    ssid = configs.getString("ssid");
    pass = configs.getString("pass");
    site = configs.getString("server");
    port = configs.getUShort("port");
    configs.end();

    siteport = site + ":" + String(port);

    //connect to wifi, error if not
    if(!connectWifi()) SOS();

    //sync time with the server
    timeWasInit = settime();

    //clear rfid buffer
    for(int i=0; i<256; i++) rfidbuff[i].active = false;

    //beep a second time to let the user know that it's ready for rfid
    notify(1);
  }
}

void loop() {
  //code for configuration mode
  if(isConfig){
    //process dns requests
    dnsServer.processNextRequest();

    //blink the light slowly to indicate access point config mode, non-blocking
    counter++;
    if(counter > 100000){
      counter = 0;
      ledOn = !ledOn;
      digitalWrite(statLed, ledOn);
    }
  }
  //code for normal operation
  else{
    //check if the config button has been pressed
    configButton();

    //read the rfid card and send data to server
    if(mfrc522.PICC_IsNewCardPresent() && mfrc522.PICC_ReadCardSerial()){
      digitalWrite(statLed, LOW);
      RFIDEvent card;
      card.tm = gettime();
      card.active = true;
      card.id = "";
      for(int i=0; i<10; i++){
        card.id += hexcodes[((mfrc522.uid.uidByte[i]) >> 4) & 0x0f];
        card.id += hexcodes[(mfrc522.uid.uidByte[i]) & 0x0f];
      }
      notify();
      Serial.print(card.id);
      Serial.print(" @ ");
      Serial.println(card.tm);
      sendrfid(card);
      mfrc522.PICC_HaltA();
    }
    digitalWrite(statLed, HIGH);

    //sync time with server every hour
    if((esp_timer_get_time() / 1000000 - setTime) > 3600){
      if(settime()) Serial.println("Time synced");
      else Serial.println("Could not sync time");
    }

    //sync time if it wasn't at least once
    if(!timeWasInit){
      checkWiFi();
      WiFiClient client;
      if(client.connect(site.c_str(), port)){
        client.stop();
        timeWasInit = settime();
      } else client.stop();
      delay(500);
    }

    //send rfid events in buffer
    if(buffread != buffwrite){
      checkWiFi();
      WiFiClient client;
      if(client.connect(site.c_str(), port)){
        client.stop();
        sendrfid(rfidbuff[buffread]);
        rfidbuff[buffread].active = false;
        buffread++;
        if(buffread >= 256) buffread = 0;
      } else client.stop();
      delay(500);
    }
  }
}

//function to send rfid data to server
bool sendrfid(RFIDEvent card){
  checkWiFi();
  WiFiClient client;

  //connect to the server, error if not
  if(!client.connect(site.c_str(), port)){
    Serial.println("Server connection failed!");
    notify(2);

    if(rfidbuff[buffwrite].active){
      Serial.println("Out of rfid buffer space");
      notify(2);
    } else{
      rfidbuff[buffwrite] = card;
      buffwrite++;
      if(buffwrite >= 256) buffwrite = 0;
    }
  } else{
    client.print("POST /api?action=rfidevent HTTP/1.1\r\nHost: ");
    client.print(siteport); //"localhost:8080"
    client.print(
      "\r\n"
      "User-Agent: Mozilla/5.0 (X11; Ubuntu; Linux x86_64; rv:57.0) Gecko/20100101 Firefox/57.0\r\n"
      "Accept: text/html,application/xhtml+xml,application/xml;q=0.9,*/*;q=0.8\r\n"
      "Accept-Language: en-US,en;q=0.5\r\n"
      "Accept-Encoding: gzip, deflate\r\n"
      "Content-Type: application/x-www-form-urlencoded\r\n"
      "Content-Length: 59\r\n"
      "Connection: keep-alive\r\n"
      "Upgrade-Insecure-Requests: 1\r\n"
      "\r\n"
      "node=");
    client.print(uuid);
    client.print("&time=");
    client.print(card.tm); //"001522108861"
    client.print("&id=");
    client.print(card.id); //"00112233445566778899"
    //node=001122334455&time=001522108861&id=00112233445566778899

    //check if the server agrees, wait up to 30 seconds
    for(int i=0; i<300; i++){
      if(!client.connected()) break;
      if(client.available()){
        String t = client.readString();
        if(t.indexOf("success") == -1) notify(2);

        client.stop();
        return true;
      }
      delay(100);
    }
  }
  
  client.stop();
  return false;
}

//function to sync time with server
bool settime(){
  checkWiFi();
  WiFiClient client;

  if(client.connect(site.c_str(), port)){
    client.print("GET /api?action=gettime HTTP/1.1\r\nHost: ");
    client.print(siteport); //"localhost:1234"
    client.print(
      "\r\nUser-Agent: Mozilla/5.0 (X11; Ubuntu; Linux x86_64; rv:59.0) Gecko/20100101 Firefox/59.0\r\n"
      "Accept: text/html,application/xhtml+xml,application/xml;q=0.9,*/*;q=0.8\r\n"
      "Accept-Language: en-US,en;q=0.5\r\n"
      "Accept-Encoding: gzip, deflate\r\n"
      "DNT: 1\r\n"
      "Connection: keep-alive\r\n"
      "Upgrade-Insecure-Requests: 1\r\n\r\n");

    for(int i=0; i<300; i++){
      if(!client.connected()) break;
      if(client.available()){
        setTime = esp_timer_get_time() / 1000000;
        
        String t = client.readString();
        t = t.substring(t.lastIndexOf("\r\n\r\n") + 4);
        Serial.print("Got time: ");
        Serial.println(t);

        servTime = 0;
        for(int j=0; j<t.length(); j++){
          servTime *= 10;
          servTime += t.charAt(j) - 48;
        }
        client.stop();
        return true;
      }
      delay(100);
    }
  } else{
    Serial.println("Server connection failed!");
    notify(2);
  }

  client.stop();
  return false;
}

//helper function to get current time padded
String gettime(){
  String ntime = "000000000000";
  uint64_t nowtime = esp_timer_get_time() / 1000000 - setTime + servTime;
  for(int i=11; i>=0; i--){
    ntime.setCharAt(i, (char)(nowtime % 10 + 48));
    nowtime /= 10;
  }
  return ntime;
}

//helper function to connect to wifi
bool connectWifi(){
  Serial.print("Connecting to WiFi: ");
  Serial.print(ssid);
  digitalWrite(statLed, HIGH);
  int count = 0;
  //WiFi.config();
  //!!!!!!!!!!!!!!!!!!!!!!!!!!!!!!!!!!!!!!!!!!!!!!!!!!!!!!!!!!!
  WiFi.begin(ssid.c_str(), pass.c_str());
  while(WiFi.status() != WL_CONNECTED){
    digitalWrite(statLed, LOW);
    delay(500);
    digitalWrite(statLed, HIGH);
    delay(500);
    Serial.print('.');
    configButton();
    count++;
    if(count >= 60){
      Serial.println();
      Serial.println("WiFi connection failed!");
      return false;
    }
  }
  Serial.println("");
  Serial.print("Connected with IP ");
  Serial.println(WiFi.localIP());
  return true;
}

//helper function to check wifi connection and handle if problem
void checkWiFi(){
  if(WiFi.status() != WL_CONNECTED){
    Serial.println("No WiFi Connection");
    SOS();
  }
}

//activates config mode if button is pressed
void configButton(){
  if(digitalRead(configPin)){
    configs.begin("wificreds", false);
    configs.putBool("isConfig", true);
    configs.end();
    for(int i=0; i<2; i++){
      notify(1);
      delay(1000);
    }
    ESP.restart();
  }
}

//flashes the light to indicate not connected to WiFi, tries to reconnect
void SOS(){
  notify(2);
  digitalWrite(statLed, LOW);
  WiFi.disconnect();
  WiFi.begin(ssid.c_str(), pass.c_str());
  delay(3000);
  int one[9] = {1,1,1,3,3,3,1,1,1};
  int two[9] = {1,1,1,1,1,1,1,1,10};
  int counter = 0;
  while(WiFi.status() != WL_CONNECTED){
    for(int i=0; i<9; i++){
      digitalWrite(statLed, HIGH);
      delay(100*one[i]);
      digitalWrite(statLed, LOW);
      delay(100*two[i]);
    }
    counter++;
    if(counter >= 18){
      Serial.println("Trying to connect again");
      notify(2);
      WiFi.disconnect();
      WiFi.begin(ssid.c_str(), pass.c_str());
      counter = 0;
    }
    configButton();
  }
}

//generates a tone, used for status noises
void beep(int freq, int len){
  freq >>= 1;
  for(int i=0; i<len; i++){ //push-pull arrangement
    digitalWrite(tone1, HIGH);
    digitalWrite(tone2, LOW);
    delayMicroseconds(freq);
    digitalWrite(tone1, LOW);
    digitalWrite(tone2, HIGH);
    delayMicroseconds(freq);
  }
  digitalWrite(tone1, LOW);
  digitalWrite(tone2, LOW);
}

//returns a list of scanned ssids for the configuration form
String getSSID(){
  String resp = "";
  int n = WiFi.scanNetworks();
  for(int i=0; i<n; i++){
    resp += WiFi.SSID(i);
    resp += ":::::";
  }
  return resp;
}

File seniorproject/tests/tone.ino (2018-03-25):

const int ledpin = 2;
const int tone1 = 15;
const int tone2 = 4;

void setup() {
  pinMode(ledpin, OUTPUT);
  pinMode(tone1, OUTPUT);
  pinMode(tone2, OUTPUT);
}

void beep(int freq, int len){
  freq >>= 1;
  for(int i=0; i<len; i++){ //push-pull arrangement, louder
    digitalWrite(tone1, HIGH);
    digitalWrite(tone2, LOW);
    delayMicroseconds(freq);
    digitalWrite(tone1, LOW);
    digitalWrite(tone2, HIGH);
    delayMicroseconds(freq);
  }
  digitalWrite(tone1, LOW);
  digitalWrite(tone2, LOW);
}

void loop() {
  beep(500, 200); //success
  beep(1000, 100);
  delay(3000);
  
  beep(10000, 100); //config set
  delay(3000);

  beep(1000, 125); //access point activated
  beep(500, 250);
  beep(333, 375);
  delay(3000);
  
  for(int i=0; i<50; i++){ //failure
    beep(1000, 10);
    delay(10);
  }
  delay(3000);
}

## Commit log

2018-03-25 Almost legit RFID firmware
    I integrated the access point test into the current rfid firmware so that pressing a button launches the ESP32 into config mode, I also made the ESP32 send HTTP POST data to the server regarding the 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
2018-03-26 Added a few missing images
    Just some images that I thought should go here, one is of the inspiration for the casing of the device, one is the current device prototype, and one is what the config interface looks like now.
2018-03-31 Past week's development
    All the files that I worked on throughout the past week.
    [MSFT.csv, MSFT_events.csv, TXN.csv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]
2018-04-01 Day 4 (?) of development
    Finished the firmware for the RFID node, uploaded some 3D printing test files, added some pictures of everything.
    [snap2.fcstd, snaplid.fcstd, snaplid.stl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]
2018-04-02 Worked on interface
    Just did some work on the HTML UI for management.
    [MSFT.csv, MSFT_events.csv, TXN.csv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]
2018-04-07 Past week of development
    Pretty much just working on the design of the case for the RFID hardware, along with some tests for how the latching mechanism works.
    [case.fcstd, case.stl, casebottom.fcstd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]
2018-04-15 Work from this week
    Worked on mainly the web interfaces.
    [casepin.fcstd, casepin.stl]
2018-05-26 Work for the week
    Added a lot to report, updated power point, fixed formatting stuff in progress reports.
2018-05-27 Worked on report
    Just worked on the report, finished the firmware design section, researched the pin latch mechanism that I used.
2018-05-29 Worked on report
    Worked on the report some more, prepared some stuff for documenting the server API.
    [api.ods]
2018-06-15 Officially not school related
    The first commit that is not for the development of the school project anymore. Also fixed a tiny bug in the users page.
    [MSFT.csv, MSFT_events.csv, TXN.csv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]
2019-04-01 Actually worked on report
    Merged the design and implementation chapters, added more detail and pictures for the implementation parts, started the software part, created db wireframe.
2019-04-08 Add BOM, start server section, make minor updates
    Added the BOM and updated the hardware section to talk about it.
    Started the server section.
    Added a file to store notes on how the server works.
    Made tweaks to SQL query table.
    [api.ods]
